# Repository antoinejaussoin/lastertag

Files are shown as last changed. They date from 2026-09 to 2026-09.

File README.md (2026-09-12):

# Lastertag

An open, custom-built laser-tag system based on the Raspberry Pi Pico 2 W.

> Despite the name, this project uses eye-safe infrared LEDs rather than laser
> diodes. Never substitute a laser module for the infrared emitter.

The initial reference build supports two players and is designed to scale to
`N` players. Each player has:

- one Pico 2 W controlling the gun, display, and all body sensors;
- four wired, body-mounted infrared receiver zones.

A local web application coordinates games, displays live statistics, and
persists match history.

## Repository layout

- [`projects/lasertag/source/`](projects/lasertag/source/) — embedded firmware, shared protocol code, and web app
- [`projects/lasertag/hardware/`](projects/lasertag/hardware/) — electronics notes and future 3D-printable parts
- [`projects/temperature-display/`](projects/temperature-display/) — first hardware sandbox: Pico 2 W temperature on the OLED
- [`projects/ir-capture/`](projects/ir-capture/) — TSOP38238 sandbox: TV-remote capture on the OLED and HTTP POST
- [`projects/gun/`](projects/gun/) — handheld laser-tag gun: ir-sender firmware in a printable Glock-17 shell
- [`docs/`](docs/) — architecture, project plan, and purchasing guide

Start with the [high-level plan](docs/high-level-plan.md), then use the
[shopping list](docs/shopping-list.md) for the two-player prototype. The
[Pico 2 W capabilities guide](docs/pico-w-capabilities.md) explains what runs
on each player controller, its memory, storage, networking, and limitations.

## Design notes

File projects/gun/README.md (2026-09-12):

# Laser-tag gun

Handheld IR gun based on the [`ir-sender`](../ir-sender/) experiment. Firmware
is the same NEC button-to-LED behaviour for now; hardware diverges into a
soldered assembly and a Glock 17–proportioned printable shell.

Leave [`ir-sender`](../ir-sender/) and [`ir-capture`](../ir-capture/) as they
are. This folder is the place to evolve the gun.

## What you need

Electronics you already have (shopping list):

- Raspberry Pi Pico 2 W (with headers)
- 0.96" I²C OLED
- Vishay TSAL6200 IR LED
- BC337-40, two 15 Ω (1 W), one 220 Ω, one 10 kΩ
- 100 nF ceramic and 4.7 µF electrolytic (decoupling at the LED)
- Diptronics DTS-644K tactile switch (trigger)
- 500 mAh LiPo with JST-PH

Extras for the permanent build (see [`hardware/README.md`](hardware/README.md)):

- soldering tools, stranded hookup wire, heat-shrink
- JST-PH 2.0 mm female pigtail
- Schottky diode (1N5817 or similar) for battery → VSYS
- M2×8 screws, bright filament + orange for the muzzle

The Adafruit PiCowbell stays on the bench as a **charging dock**. It does not
fit in the grip. Remove the dummy magazine, unplug the cell, charge on the
PiCowbell.

## Pin map (unchanged from ir-sender)

| Function | Pico | Notes |
|---|---|---|
| OLED SDA | GP16 | I²C |
| OLED SCL | GP17 | I²C |
| IR LED base drive | GP18 | through 220 Ω → BC337 |
| Trigger | GP19 | to GND through the switch; internal pull-up |
| Logic supply | 3V3 (pin 36) | OLED and IR LED path |
| Ground | GND (pin 38) | common |
| Battery | VSYS (pin 39) | via Schottky from the mag JST |
| USB 5 V | VBUS (pin 40) | leave empty |

## Hardware and CAD

- [`hardware/README.md`](hardware/README.md) — gap list, power rules, soldering
- [`hardware/connections.svg`](hardware/connections.svg) — soldered nets (no breadboard)
- [`cad/README.md`](cad/README.md) — print settings and assembly
- [`cad/gun.scad`](cad/gun.scad) — printable Glock-17-proportioned shell

## Safety

- Infrared LED only. Never substitute a laser diode.
- Power the OLED and IR LED from **3.3 V**, not `VBUS`.
- Battery `+` goes through a Schottky diode into **VSYS**. Never wire the cell
  straight across USB 5 V.
- **Remove the magazine before plugging Micro-USB into the Pico.**
- Charge the LiPo on the PiCowbell where you can watch it. Do not use a
  swollen, punctured, or hot cell.

## What the firmware does

Same as ir-sender: each trigger press sends three NEC frames (address `0x42`,
command random 1–10). The OLED shows `gun` / `ready` / `sent 42:xx`. Optional
USB serial `debug on` / `save` toggles DC / 1 s beacon modes for a meter.

Point the muzzle at an [`ir-capture`](../ir-capture/) board; it should show
`42:01`–`42:0A`.

## Build and upload

1. Hold **BOOTSEL** on the Pico, plug USB (cable must be data-capable), release.
2. Finder should show **RP2350**.
3. From the repository root:

```bash
cd projects/gun
make
```

That builds `gun.uf2` and copies it onto the drive. Or `make uf2` and drag the
file yourself.

First build downloads crates and can take several minutes.

## USB serial

```bash
ls /dev/cu.usbmodem*
screen /dev/cu.usbmodem* 115200
```

Banner: `Pico 2 W gun`. Leave `screen` with `Ctrl-A` then `K`, then `Y`.

## Next steps (not this folder yet)

Game firmware, Wi-Fi, body receivers, and the player pin map (GP0 / GP2 / …)
live later under `projects/lasertag/`. Keep this pinout until then so the
soldered harness stays compatible with the current UF2.

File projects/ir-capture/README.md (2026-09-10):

# IR-capture experiment

A standalone hardware test, separate from the laser-tag firmware. It reads a
Vishay TSOP38238 38 kHz infrared receiver, shows each captured remote button
on the 0.96" I²C OLED, and POSTs the same event to the HTTP listener used by
[`temperature-display`](../temperature-display/).

You do not need to know Rust or electronics already. Follow the steps in order.
If the OLED is already wired from the temperature test, leave those four wires
and add only the receiver.

## What you need

- Raspberry Pi Pico 2 W (RP2350 plus onboard 2.4 GHz Wi-Fi)
- a **2.4 GHz** Wi-Fi network (the Pico cannot join 5 GHz-only access points)
- 0.96" four-pin I²C OLED (the same module as the temperature test)
- Vishay TSOP38238 38 kHz IR receiver (Pi Hut)
- 100 Ω resistor, 100 nF ceramic capacitor, and 4.7 µF electrolytic capacitor
  from the shopping list (the TSOP supply filter)
- a TV remote, or any 38 kHz IR remote
- the full-size breadboard and jumper wires from the shopping list
- a **data** USB cable (charge-only cables will not work)

The PiCowbell and LiPo are not used for this test. USB powers the Pico.

## Safety

- Unplug USB while you insert parts.
- Power the OLED and the TSOP from **3.3 V only**. Do not use `VBUS`
  (physical pin 40, the 5 V USB pin).

## How to plug it together

Two drawings in this folder:

- [`connections.svg`](connections.svg) — what joins to what, no breadboard
- [`wiring.svg`](wiring.svg) — the same circuit, hole by hole on the breadboard

Useful references:

- [Interactive Pico pinout](https://pico.pinout.xyz/) — choose Pico 2 W; hover GP16, GP17, GP18, 3V3, GND
- [Pi Hut TSOP38238](https://thepihut.com/products/ir-infrared-receiver-tsop38238)
- [Vishay TSOP382 datasheet](https://www.vishay.com/docs/82491/tsop382.pdf) — pin 1 `OUT`, pin 2 `GND`, pin 3 `VS`
- [Pi Hut 0.96" OLED](https://thepihut.com/products/0-96-oled-display-module-128x64)
- [Raspberry Pi Pico getting started](https://www.raspberrypi.com/documentation/microcontrollers/pico-series.html) — BOOTSEL / UF2 upload

### TSOP38238 pinout

Hold the part with the **rounded lens toward you** and the three legs pointing
down. Left to right:

| Leg | Name | Goes to |
|---|---|---|
| left | `OUT` | Pico `GP18` (physical pin 24) |
| middle | `GND` | Pico `GND` (physical pin 38) |
| right | `VS` | Pico `3V3` through 100 Ω, with capacitors to `GND` |

The output is idle-high and goes low while a 38 kHz burst is in view. The chip
has an internal pull-up; firmware also enables the Pico pull-up.

### Assembly

Unplug USB. Hold the breadboard so **printed column 1 is on the left**. Follow
[`wiring.svg`](wiring.svg) hole for hole. Yellow holes on the drawing already
have something in them.

1. Sit the Pico 2 W **across the centre trench**, like a DIP chip. USB hangs
   off the left so the cable still fits. 20 pins go in **row e** (columns 1–20)
   and 20 pins go in **row f**. The antenna is at column 20.

   | Pico pin | Hole | Name |
   |---|---|---|
   | 1 | `e1` | GP0 |
   | 21 | `f20` | GP16 (SDA) |
   | 22 | `f19` | GP17 (SCL) |
   | 24 | `f17` | GP18 (IR) |
   | 36 | `f5` | 3V3 |
   | 38 | `f3` | GND |
   | 40 | `f1` | VBUS — leave empty |

2. Power the long rails from the Pico, then join top and bottom:

   | Colour | From | To |
   |---|---|---|
   | red | `j5` | bottom `+3V3` rail |
   | black | `j3` | bottom `GND` rail |
   | red | bottom `+` column 35 | top `+` column 35 |
   | black | bottom `GND` column 34 | top `GND` column 34 |

3. OLED pins in **`a23` `a24` `a25` `a26`**. Typical Pi Hut order is
   `VCC`, `GND`, `SCL`, `SDA`. If your module prints a different order, keep
   those four holes and move the wires to the printed names.

   The screen uses the **same GPIOs as temperature-display**: `GP16` (SDA) and
   `GP17` (SCL). If those four wires already work, leave them.

   | OLED name | Hole | Jumper |
   |---|---|---|
   | `VCC` | `a23` | top `+3V3` rail |
   | `GND` | `a24` | top `GND` rail |
   | `SCL` | `e25` | `g19` (GP17) |
   | `SDA` | `e26` | `g20` (GP16) |

4. TSOP38238 legs in **`c28` `c29` `c30`**. Lens toward you (toward the
   trench). With the lens facing you, left to right is `OUT`, `GND`, `VS`.

   | Part | Holes |
   |---|---|
   | TSOP `OUT` / `GND` / `VS` | `c28` / `c29` / `c30` |
   | orange jumper `OUT` → GP18 | `d28` → `g17` |
   | black jumper TSOP `GND` | `a29` → top `GND` rail |
   | 100 Ω from `+3V3` into `VS` | top `+` column 30 → `a30` |
   | 100 nF ceramic | `d30` – `d31` (either way) |
   | 4.7 µF electrolytic | `e30` (+) – `e31` (stripe / minus) |
   | black jumper, capacitor return | `a31` → top `GND` rail |

Do not add extra links between columns 28, 29, and 30. That would short `OUT`
or `VS` to `GND`.

The 100 Ω resistor has no polarity. The ceramic capacitor (often marked `104`)
has no polarity. The electrolytic can is polarized: the stripe is negative.

Rows `a`–`e` in one numbered column are already joined. Rows `f`–`j` in that
column are a second, separate strip. That is why a jumper in `g17` is already
connected to Pico pin 24 in `f17`.

The receiver uses `GP18` so it sits on the same Pico edge as the OLED (`GP16`
and `GP17`). The later player board maps body receivers to `GP10`–`GP13`
instead.

## What the firmware does

The TSOP38238 demodulates 38 kHz infrared. The program waits for a burst,
records mark/space times, and:

- decodes **Samsung** TV remotes (`S` plus address and command in hex);
- decodes **NEC** remotes (address and command in hex);
- shows anything else as the first two pulse times in milliseconds;
- treats a held Samsung or NEC button as a repeat (` r` on the OLED).

If the first burst does not decode (TSOP AGC, or a copy caught mid-frame),
the firmware waits for the sender’s extra copies before showing `raw`.

The title ends with **`H`** or **`L`**: the receiver output is idle-high, so
`H` means the pin looks healthy. `L` at rest means `OUT` is stuck low
(wrong pin, swapped `OUT`/`VS`, or a short). The number at the top right
counts each logical message (a held remote ` r` does not add another; the
sender’s three NEC copies count as one).

Wi-Fi SSID, password, and the HTTP POST URL are **not** compiled in. You type
them over USB serial; `save` stores them in flash. After a reboot they are
still there. Flash layout matches `temperature-display`, so a Pico that was
already provisioned for that project keeps its Wi-Fi settings.

Once joined, each captured button POSTs JSON to that URL, for example:

```json
{"proto":"samsung","addr":57504,"cmd":26,"rep":false}
```

```json
{"proto":"nec","addr":32,"cmd":13,"rep":false}
```

or, if the burst is neither:

```json
{"proto":"raw","n":67,"lead":[4500,4500]}
```

The onboard LED (on the wireless chip) turns on when Wi-Fi is up.

## Install the software tools (once)

Same tools as [`temperature-display`](../temperature-display/README.md). If
Rust is already installed, skip to **Build and upload**.

### 1. Install Rust

On macOS, in Terminal:

```bash
curl --proto '=https' --tlsv1.2 -sSf https://sh.rustup.rs | sh
```

Follow the prompts (the default options are fine). Then close Terminal and open
a new one, or run:

```bash
source "$HOME/.cargo/env"
```

Check:

```bash
rustc --version
cargo --version
```

### 2. Add the Pico 2 W CPU target

This crate’s `rust-toolchain.toml` asks `rustup` to install
`thumbv8m.main-none-eabihf` when you enter the folder. You can also install it
yourself:

```bash
rustup target add thumbv8m.main-none-eabihf
```

That target is the Pico 2 W’s ARM Cortex-M33 CPU.

## Build and upload

Put the Pico 2 W in bootloader mode first:

1. Unplug the USB cable.
2. Hold the **BOOTSEL** button on the Pico (the small button next to the USB
   socket).
3. Plug the USB cable in while still holding BOOTSEL.
4. Release BOOTSEL.
5. Finder should show a drive called **RP2350**.

If nothing appears, the cable is probably charge-only. Try another cable.

Then, from the `lastertag` repository root:

```bash
cd projects/ir-capture
make
```

That compiles the firmware, converts it to a `.uf2`, and copies it onto the
Pico. The `RP2350` drive disappears; that is normal. The program starts
immediately.

The first build downloads crates and can take several minutes. After that,
`make` is the only command you need when the board is already in BOOTSEL.

If `make` builds the UF2 but cannot copy it, drag `ir-capture.uf2` onto the
**RP2350** drive in Finder.

If you only want the files without copying them onto the board:

```bash
make build   # ELF only
make uf2     # ELF plus ir-capture.uf2
```

## What you should see

Text on the OLED, similar to:

```text
IR capture  H          0
  ready
USB: wifi/save
```

Point a TV remote at the TSOP lens and press a button. A Samsung TV remote
usually looks like this (address is often `E0E0`):

```text
IR capture  H          1
  S E0E0:1A
wifi ok  post ok
```

A typical NEC remote shows address and command without the `S`:

```text
IR capture  H          2
  20:0D
wifi ok  post ok
```

Holding the button adds ` r`. Other 38 kHz encodings show the first two
pulse lengths, for example `4.5 4.5 67` (milliseconds, then edge count).

The bottom line is status: `joining wifi`, `wifi ok`, `wifi fail`, or
`wifi ok  post ok` after a successful POST.

On a dual-colour 0.96" panel the top band is yellow and the rest is blue.
The title sits in the yellow band; the hex value is blue. That is the glass,
not a wiring fault.

If every press shows times like `4.5 4.5` instead of `S …`, the header is
Samsung-like but the bit timings did not match; the JSON still has the lead
times.

## USB Wi-Fi and server setup

Flash the board, wait until the OLED is showing `ready`, then open a serial
terminal. On macOS:

```bash
ls /dev/cu.usbmodem*
screen /dev/cu.usbmodem* 115200
```

If several `usbmodem` devices appear, try each until you see a `>` prompt.
Type `help`. Leave `screen` with `Ctrl-A` then `K`, then `Y`.

On this computer, start a listener (binds all interfaces, port 8090). This is
the same program as in `temperature-display`; you only need one copy running:

```bash
bun listen_post.ts
```

It prints this machine’s LAN IP. On the Pico console, using that IP:

```text
wifi YourNetworkName
psk YourPassword
server 192.168.1.23:8090/ir
save
```

You can keep path `/temp` if this Pico was already set up for the temperature
project; the listener accepts any POST path. `psk` with no password means an
open network. `server` can also be a hostname (`nas.local:8090/ir`). The Pico
is 2.4 GHz only.

`save` writes flash and starts joining. `show` prints the current RAM copy.
`clear` wipes the saved settings. After `save`, you can unplug USB and power
from the PiCowbell; the board still has the settings.

Press a remote button. The listener should print a JSON body. The Pico talks
to your **LAN IP**, not `localhost`.

SH1106 panels have 132 columns of RAM and 128 visible. This firmware starts
the write window at column 0 so the left edge is not leftover RAM. If a 2-pixel
bar appears on the **right** instead, change `with_column_offset(0)` in
`src/display.rs` to `with_column_offset(2)` and flash again.

## If the title is readable but the rest is noise

The firmware talks to the panel as an **SH1106** (132-column RAM). Cheap
yellow/blue 0.96" modules are often SH1106 even when the listing says
SSD1306. Driving SH1106 as SSD1306 commonly leaves the first rows readable
and fills the blue area with random pixels.

Reflash this folder with BOOTSEL + `make`. If the value is still garbage, in
`src/display.rs` change `OledConfig::sh1106_128x64()` to
`OledConfig::ssd1306_128x64()` and flash again.

## If the screen stays black

- USB is plugged into the Pico (the board is powered from that cable).
- Every OLED label matches the table. Swapping SDA/SCL is the most common
  mistake.
- `VCC` is on **3V3** (pin 36), not **VBUS** (pin 40).
- You counted pins from the USB end. `GP16`/`GP17` are on the **right** side,
  at the end opposite the USB plug.
- You actually copied a UF2 (the `RP2350` drive vanished after the copy).
- Some modules use I²C address `0x3D` instead of `0x3C`. In `src/display.rs`,
  change the `0x3C` passed to `Oled::new` to `0x3D`.
- The plastic film on a new OLED can make it look dim; peel it off.

## If nothing happens when you press the remote

Samsung remotes are the usual case here. Older IR-only Samsung remotes speak
**Samsung32** (not NEC). This firmware decodes that after you reflash. Many
**Samsung Smart / One Remote** handsets are Bluetooth: only a few keys still
emit IR (often **Power**). Try Power first, close to the lens. A cheap IR-only
TV remote is a better test.

Also check:

- You flashed **this** folder after the `GP18` pin change (`BOOTSEL` + `make`).
  An older UF2 still listens on a different GPIO.
- The title shows **`H`** at rest. If it shows **`L`**, `OUT` is stuck low:
  confirm the orange jumper is `d28` → `g17` (Pico pin 24 / `GP18`), and that
  the TSOP legs are `OUT`, `GND`, `VS` left to right with the lens toward you.
  Swapping `OUT` and `VS` can make the part hot; unplug USB and recheck.
- The first press after a long idle can be eaten by the TSOP AGC. Press again.
- `VS` is 3.3 V through 100 Ω, not 5 V. The electrolytic stripe is on **GND**.
- The TSOP38238 is a 38 kHz part. It ignores 56 kHz gadgets; 36 kHz remotes
  only work at very short range.
- Range is typically tens of centimetres to a few metres. Point at the **lens**,
  not the Pico or the table, and avoid a bright lamp straight into the lens.

## Changing the program

Edit `src/main.rs` or `src/ir.rs`, save, put the Pico back in BOOTSEL, then
`make` again.

This folder is only a sandbox. Game firmware will live later under
`projects/lasertag/source/firmware/`.

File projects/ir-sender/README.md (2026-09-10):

# IR-sender experiment

A standalone hardware test, separate from the laser-tag firmware. It sits on
the **second** Pico 2 W. Press a button and it blinks the infrared LED with a
NEC remote code. The [`ir-capture`](../ir-capture/) board should show `42:01`–`42:0A`.

Leave ir-capture assembled. Do not unplug that breadboard.

You do not need to know Rust or electronics already. Follow the steps in order.

## What you need

- the **second** Raspberry Pi Pico 2 W (keep the first one running ir-capture)
- 0.96" four-pin I²C OLED (the second module from the shopping list)
- Vishay TSAL6200 940 nm IR LED (Rapid)
- one Diotec **BC337-40** transistor
- two **15 Ω, 1 W** resistors (brown-green-black)
- one **220 Ω** resistor (red-red-brown) — GPIO to the transistor **base** only
- one **10 kΩ** resistor (brown-black-orange) — base to GND
- one tactile push button (Diptronics DTS-644K)
- the second full-size breadboard and jumper wires
- a **data** USB cable (charge-only cables will not work)

The PiCowbell and LiPo are **not** used here. USB powers the Pico.

## Safety

- Unplug USB while you insert parts.
- Power the OLED from **3.3 V only**. Do not use `VBUS` (physical pin 40, the
  5 V USB pin).
- The two 15 Ω resistors feed the LED from **3.3 V** through the transistor.
  Never put a 15 Ω resistor on GP18. The 220 Ω is only between GP18 and the
  base.

## How to plug it together

Two drawings in this folder:

- [`connections.svg`](connections.svg) — three diagrams (OLED, button, TSAL), Pico on each, no breadboard
- [`wiring.svg`](wiring.svg) — the same circuit, hole by hole on the breadboard

Useful references:

- [Interactive Pico pinout](https://pico.pinout.xyz/) — choose Pico 2 W; hover GP16, GP17, GP18, GP19, 3V3, GND
- [Pi Hut 0.96" OLED](https://thepihut.com/products/0-96-oled-display-module-128x64)
- [Vishay TSAL6200](https://www.rapidonline.com/vishay-tsal6200-5mm-940nm-ir-transmitter-diode-49-4513) — long lead is the anode
- [Raspberry Pi Pico getting started](https://www.raspberrypi.com/documentation/microcontrollers/pico-series.html) — BOOTSEL / UF2 upload

### TSAL6200 pinout

Looks like a clear or smoke-grey 5 mm LED:

| Leg | Name | Goes to |
|---|---|---|
| long | anode (`A`) | two 15 Ω from `+3V3` |
| short, next to the flat rim | cathode (`K`) | BC337 collector |

### BC337-40 pinout

Small black TO-92, one flat face, three legs. For the Diotec part, with the
**flat toward you** and the legs down, the order is **C-B-E** (left to right).
On this breadboard, point the flat at the **trench** and use
`c26` = C, `c25` = B, `c24` = E. All IR parts stay in rows `a`–`d`.

### Assembly

Unplug USB. Hold the breadboard so **printed column 64 is on the left** (Pico /
USB) and **column 1 is on the right**. The Pico sits **lower**: pins in **row
`e`** (above the trench) and **row `j`** (below the trench). On this board the
lower letters run `j` `i` `h` `g` `f` from the trench down. Top rails are `+`
then `−`. After row `f`, the bottom rails are `+` then `−` at the very bottom.

Follow [`wiring.svg`](wiring.svg) hole for hole. Yellow holes on the drawing
already have something in them. If your last printed number is 63, not 64,
shift every hole one column toward the Pico.

1. Sit the Pico 2 W **across the centre trench**, like a DIP chip. USB hangs
   off the left at column 64 so the cable still fits. 20 pins go in **row e**
   (columns 64–45) and 20 pins go in **row j**. The antenna is at column 45.

   With the chip facing you and USB on the left, the **top** row (e) is pins
   40–21 and the **bottom** row (j) is pins 1–20. GP16–GP19 are on the top.

   | Pico pin | Hole | Name |
   |---|---|---|
   | 40 | `e64` | VBUS — leave empty |
   | 38 | `e62` | GND |
   | 36 | `e60` | 3V3 |
   | 25 | `e49` | GP19 (button) |
   | 24 | `e48` | GP18 (IR LED) |
   | 23 | `e47` | GND — skip this column |
   | 22 | `e46` | GP17 (SCL) |
   | 21 | `e45` | GP16 (SDA) |
   | 1 | `j64` | GP0 |

2. Power the long rails from the Pico, then join top and bottom:

   | Colour | From | To |
   |---|---|---|
   | red | `a60` | top `+` rail |
   | black | `a62` | top `−` rail |
   | red | bottom `+` column 20 | top `+` column 20 |
   | black | bottom `−` column 19 | top `−` column 19 |

3. OLED pins in **`a42` `a41` `a40` `a39`**, from the Pico toward column 1.
   Typical Pi Hut order is `VCC`, `GND`, `SCL`, `SDA`. If your module prints a
   different order, keep those four holes and move the wires to the printed
   names.

   | OLED name | Hole | Jumper |
   |---|---|---|
   | `VCC` | `a42` | top `+` rail |
   | `GND` | `a41` | top `−` rail |
   | `SCL` | `c40` | `c46` (GP17) |
   | `SDA` | `d39` | `d45` (GP16) |

4. IR driver on the **top** half (rows `a`–`d`), **to the right of the OLED**.
   Q1 needs three consecutive holes of its own. Unplug USB first. Pull the old
   IR parts if they were in columns 37–32 — those holes stacked the LED on
   top of Q1, so the middle leg (B) often never sat in its strip.

   | Part | Holes |
   |---|---|
   | BC337-40, flat toward the trench | `c26` C, `c25` B, `c24` E |
   | red jumper +3V3 → first 15 Ω | top `+` column 37 → `b37` |
   | 15 Ω | `b37` – `b32` |
   | 15 Ω | `b32` – `b28` |
   | TSAL6200 anode / cathode | `c28` / `c26` (cathode shares C) |
   | orange jumper GP18 → 220 Ω | `b48` → `d21` |
   | 220 Ω (base) | `d21` – `d25` |
   | 10 kΩ base pull-down | `a25` → top `−` rail |
   | black jumper emitter → GND | `a24` → top `−` rail |

   Long LED lead in `c28`. Short lead and flat rim in `c26`.

   A meter on **B** (`c25`) while GP18 is high must read about **0.7 V**. If
   that hole is still **3.3 V**, the middle transistor leg is not in `c25`.

   Bands: 15 Ω is **brown-green-black**. 220 Ω is **red-red-brown**. 10 kΩ is
   **brown-black-orange**. A 15 Ω on GP18 can damage the Pico.

5. Button across the trench (legs in `e` and `j`). On this 6×6 part the
   **6.5 mm** pins are already joined inside the switch. Those pins are the
   ones that span the trench, so `e31` is permanently connected to `j31`.
   Ground must **not** be on `j31` — that holds GP19 low forever.

   GP19 and GND both sit on the **top** half, two columns apart. Press joins
   column 31 to column 29.

   | Part | Holes |
   |---|---|
   | button legs | `e31` `e29` `j31` `j29` |
   | purple jumper GP19 | `d49` → `d31` |
   | black jumper to GND | `d29` → top `−` rail |

   Leave `j31` without a GND wire. Keep the switch off column 32 (15 Ω
   midpoint).

Rows `a`–`e` in one numbered column are already joined. Rows `j`–`f` in that
column are a second, separate strip. That is why a jumper in `b48` is already
connected to Pico GP18 in `e48`.

## What the firmware does

GP18 is a GPIO into the BC337 base. Marks are a 38 kHz square wave on that
pin; spaces are the pin low (transistor off). The LED itself runs from 3.3 V
at about 58 mA. On each button press the program sends three **NEC** frames: address
`0x42` and a **command rolled at random from 1 to 10**. ir-capture already
understands that encoding, so its OLED should show `42:01` … `42:0A` and
its HTTP POST looks like:

```json
{"proto":"nec","addr":66,"cmd":7,"rep":false}
```

(`cmd` is decimal 1–10.) The Pico’s onboard LED lights for half a second
on each press (that LED is on the wireless chip, not the IR LED).

A held button does not repeat. Release and press again for another burst.

Boot starts at `ready`. There is no Wi-Fi on this board. A USB serial CLI
(same idea as capture’s Wi-Fi setup) can turn on a **debug** mode for a meter:

```text
debug on
save
```

Then the button toggles **`always on`** (LED DC, ~58 mA, TSOP ignores it) and
**`every 1s`** (a random NEC `42:01`–`42:0A` once a second). `debug off` then `save` returns to
one NEC per click. `show` / `clear` work like capture. After `save`, the flag
survives reboot.

Keep phones **away from the capture TSOP**. An iPhone’s Face ID / LiDAR
illuminator is also 940 nm; that chip will report short garbled `raw` bursts
that have nothing to do with this LED.

## Install the software tools (once)

Same tools as [`ir-capture`](../ir-capture/README.md). If Rust is already
installed, skip to **Build and upload**.

### 1. Install Rust

On macOS, in Terminal:

```bash
curl --proto '=https' --tlsv1.2 -sSf https://sh.rustup.rs | sh
```

Follow the prompts (the default options are fine). Then close Terminal and open
a new one, or run:

```bash
source "$HOME/.cargo/env"
```

Check:

```bash
rustc --version
cargo --version
```

### 2. Add the Pico 2 W CPU target

This crate’s `rust-toolchain.toml` asks `rustup` to install
`thumbv8m.main-none-eabihf` when you enter the folder. You can also install it
yourself:

```bash
rustup target add thumbv8m.main-none-eabihf
```

That target is the Pico 2 W’s ARM Cortex-M33 CPU.

## Build and upload

Put **this** Pico 2 W in bootloader mode first (the sender board, not the
capture board):

1. Unplug the USB cable.
2. Hold the **BOOTSEL** button on the Pico (the small button next to the USB
   socket).
3. Plug the USB cable in while still holding BOOTSEL.
4. Release BOOTSEL.
5. Finder should show a drive called **RP2350**.

If nothing appears, the cable is probably charge-only. Try another cable.

Then, from the `lastertag` repository root:

```bash
cd projects/ir-sender
make
```

That compiles the firmware, converts it to a `.uf2`, and copies it onto the
Pico. The `RP2350` drive disappears; that is normal. The program starts
immediately.

The first build downloads crates and can take several minutes. After that,
`make` is the only command you need when the board is already in BOOTSEL.

If `make` builds the UF2 but cannot copy it, drag `ir-sender.uf2` onto the
**RP2350** drive in Finder.

If you only want the files without copying them onto the board:

```bash
make build   # ELF only
make uf2     # ELF plus ir-sender.uf2
```

## What you should see

Right after flash, the **sender** OLED shows:

```text
IR sender    H
  ready
press btn
```

The title must end in **`H`** at rest. Hold the button: it should switch to
**`L`** for as long as you hold. If it is **`L` at rest**, the black GND
jumper is still on `j31` — move it to **`d29` → top −**. Do not ground `j31`.

Press the button. The onboard LED lights for 0.5 s and the line changes to
`sent 42:07` (command is random 1–10, shown in hex). The number in the top
right is how many times you have pressed.

On the **capture** Pico, pointed at this LED from a short distance:

```text
IR capture  H          1
  42:07
wifi ok  post ok
```

(`wifi ok  post ok` only if that Pico is already joined to Wi-Fi.)

On a dual-colour 0.96" panel the top band is yellow and the rest is blue.
The title sits in the yellow band. That is the glass, not a wiring fault.

## USB serial debug setup

Debug mode is **off** by default. Leave it off for the real test: one button
click sends one NEC burst and stops.

Flash the sender, wait until the OLED shows `ready`, then open a serial
terminal. On macOS:

```bash
ls /dev/cu.usbmodem*
screen /dev/cu.usbmodem* 115200
```

Capture and sender both appear as `usbmodem` devices. Try each until the
banner says `Pico 2 W IR sender`. Type `help`. Leave `screen` with `Ctrl-A`
then `K`, then `Y`.

```text
debug on
save
```

`save` writes flash and applies now. The OLED switches to `always on` (LED
DC, ~58 mA — the capture TSOP ignores DC). Press the button to toggle
`every 1s` (a random NEC `42:01`–`42:0A` once a second). Press again to go back to DC.

```text
debug off
save
```

That returns to one NEC per click. `show` prints the RAM copy. `clear` wipes
the saved flag. After `save`, the setting survives reboot.

Range is tens of centimetres, not metres. Point the LED at the TSOP **lens**.
The LED does not light visibly; infrared is outside human vision.

## If the title is readable but the rest is noise

The firmware talks to the panel as an **SH1106** (132-column RAM). Cheap
yellow/blue 0.96" modules are often SH1106 even when the listing says
SSD1306. Driving SH1106 as SSD1306 commonly leaves the first rows readable
and fills the blue area with random pixels.

Reflash this folder with BOOTSEL + `make`. If the value is still garbage, in
`src/display.rs` change `OledConfig::sh1106_128x64()` to
`OledConfig::ssd1306_128x64()` and flash again.

SH1106 panels have 132 columns of RAM and 128 visible. This firmware starts
the write window at column 0 so the left edge is not leftover RAM. If a 2-pixel
bar appears on the **right** instead, change `with_column_offset(0)` in
`src/display.rs` to `with_column_offset(2)` and flash again.

## If the screen stays black

- USB is plugged into the Pico (the board is powered from that cable).
- Every OLED label matches the table. Swapping SDA/SCL is the most common
  mistake.
- `VCC` is on **3V3** (pin 36), not **VBUS** (pin 40).
- You counted pins from the USB end. `GP16`/`GP17` are on the **top** row,
  at the end opposite the USB plug (`e45` / `e46`).
- You actually copied a UF2 (the `RP2350` drive vanished after the copy).
- Some modules use I²C address `0x3D` instead of `0x3C`. In `src/display.rs`,
  change the `0x3C` passed to `Oled::new` to `0x3D`.
- The plastic film on a new OLED can make it look dim; peel it off.

## If the OLED stays on `L` / `btn down`

GP19 is shorted to GND. On this switch the legs that cross the trench are
already joined inside the part, so a GND wire on **`j31`** holds the pin low
even when you are not pressing.

1. Unplug the black jumper from `j31`. The title should become **`H`**.
2. Plug that black jumper **`d29` → top −** (same half of the board as
   purple, one column toward the LED). Leave `j31` empty of GND.
3. Rest = `H`. Hold = `L`. Then a press sends IR.

## If the button only works rarely

Watch the title **`H` / `L`** while you press. Rest must be **`H`**.

1. Rest is `L`: follow the section above (`d29`, not `j31`).
2. Rest is `H` but a hold stays `H`: push all four legs in, reseat purple
   `d49`–`d31` and black `d29`.

## If capture shows nothing, or raw times instead of `42:xx`

- After flash, OLED must say `ready` (otherwise this UF2 is not on the board).
  Point the LED at the capture TSOP and press: you should get `42:01`–`42:0A`.
  The capture title’s right-hand number should increment once per press. For a
  meter, USB serial `debug on` then `save` — OLED `always on` is DC (capture
  will not show `L`). Button then toggles `every 1s`. Still nothing: Q1 flat
  toward the trench (`c26` C, `c25` B, `c24` E), long LED lead in `c28`, orange
  jumper from `b48` (GP18) not column 47, 15 Ω only in the 3.3 V LED path.
  If GP18 is 3.3 V but **B (`c25`) is also 3.3 V**, the middle Q1 leg is not
  in `c25` — a real base clamps at ~0.7 V.
- Do **not** hold an iPhone (or any Face ID / LiDAR phone) near the capture
  TSOP. That illuminator is 940 nm and shows up as short `raw` junk. A TV
  remote is the right “capture still works” check.
- Point the LED at the TSOP lens on the other breadboard, a few centimetres
  away. Do not aim at the Pico or the table. A phone camera is a wiring test,
  not a protocol test: 38 kHz bursts are too short and too dim to trust.
- The orange jumper must be column **48 on the top** (`b48`), the same strip
  as Pico `e48` / GP18. Column **47** on that row is GND — an easy miss.
- Long LED lead is in `c28` (anode). Cathode must sit on the collector (`c26`),
  not on GND.
- The 220 Ω is `d21`–`d25` (base). The 15 Ω pair is `b37`–`b32`–`b28`.
- You flashed **this** folder (`projects/ir-sender`) onto the sender Pico, and
  ir-capture is still running on the other Pico.
- Capture’s title shows **`H`** at rest. If it shows **`L`**, that board’s
  receiver wiring is wrong; see the ir-capture README.

## Changing the program

Edit `src/main.rs` or `src/ir.rs`, save, put the Pico back in BOOTSEL, then
`make` again.

This folder is only a sandbox. Game firmware will live later under
`projects/lasertag/source/firmware/`. The player board uses this same
transistor driver on GP0.

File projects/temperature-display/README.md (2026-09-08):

# Temperature-on-OLED experiment

A standalone first hardware test, separate from the laser-tag firmware. It
reads the temperature sensor **inside** the Raspberry Pi Pico 2 W and shows it
on the 0.96" I²C OLED.

You do not need to know Rust or electronics already. Follow the steps in order.

## What you need

- Raspberry Pi Pico 2 W (RP2350 plus onboard 2.4 GHz Wi-Fi)
- a **2.4 GHz** Wi-Fi network (the Pico cannot join 5 GHz-only access points)
- 0.96" four-pin I²C OLED (often sold as SSD1306; many yellow/blue 128×64
  modules are actually SH1106)
- the full-size breadboard and jumper wires from the shopping list
- a **data** USB cable (charge-only cables will not work)

The PiCowbell and LiPo are not used for this test. USB powers the Pico.

## Safety

- Unplug USB while you insert parts.
- Power the OLED from **3.3 V only**. Do not use `VBUS` (physical pin 40, the
  5 V USB pin).

## How to plug it together

Open the drawing in this folder:

- [`wiring.svg`](wiring.svg)

Useful references:

- [Interactive Pico pinout](https://pico.pinout.xyz/) — choose Pico 2 W; hover GP16, GP17, 3V3, GND
- [Pi Hut 0.96" OLED](https://thepihut.com/products/0-96-oled-display-module-128x64) — this module’s pins and I²C address `0x3C`
- [Raspberry Pi Pico getting started](https://www.raspberrypi.com/documentation/microcontrollers/pico-series.html) — BOOTSEL / UF2 upload

### Assembly

1. Unplug USB. Sit the Pico 2 W **across the centre gap** of the breadboard,
   like a bridge. The USB socket should hang off the top so the cable still
   fits. Count pins from that USB end. The antenna is at the opposite end
   from USB.
2. Put the OLED in four unused columns, away from the Pico, so each OLED pin
   has its own column.
3. Four jumper wires. Match the **printed names on the OLED**, not a photo of
   a different module:

   | OLED pin | Pico pin | Physical pin (USB at the top) |
   |---|---|---:|
   | `VCC` | `3V3` | 36 (fifth pin down the **right** side) |
   | `GND` | `GND` | 38 (third pin down the **right** side) |
   | `SDA` | `GP16` | 21 (bottom pin on the **right** side) |
   | `SCL` | `GP17` | 22 (second pin from the bottom on the **right** side) |

4. On a breadboard, every hole in the same numbered column (on one side of
   the gap) is already connected. Plug the jumper into the same column as the
   Pico pin, then into the OLED pin’s column.

You can ignore the long coloured power rails for this test.

## What the firmware does

The Pico 2 W has a small temperature sensor on the RP2350 silicon. The program
reads that sensor about once a second and draws the value on the OLED.

That number is the **chip** temperature. It is usually a few degrees above the
room, and it rises while the chip runs. It is not a weather reading.

Wi-Fi SSID, password, and the HTTP POST URL are **not** compiled in. You type
them over USB serial; `save` stores them in flash. After a reboot they are
still there. Once joined, the Pico POSTs `{"celsius":27.4}` about once a
minute to that URL.

The onboard LED (on the wireless chip) turns on when Wi-Fi is up.

## Install the software tools (once)

You will compile a program on your computer, then copy a small file onto the
Pico. The Pico is a microcontroller: it does not run macOS or Linux.

### 1. Install Rust

On macOS, in Terminal:

```bash
curl --proto '=https' --tlsv1.2 -sSf https://sh.rustup.rs | sh
```

Follow the prompts (the default options are fine). Then close Terminal and open
a new one, or run:

```bash
source "$HOME/.cargo/env"
```

Check:

```bash
rustc --version
cargo --version
```

### 2. Add the Pico 2 W CPU target

This crate’s `rust-toolchain.toml` asks `rustup` to install
`thumbv8m.main-none-eabihf` when you enter the folder. You can also install it
yourself:

```bash
rustup target add thumbv8m.main-none-eabihf
```

That target is the Pico 2 W’s ARM Cortex-M33 CPU.

## Build and upload

Put the Pico 2 W in bootloader mode first:

1. Unplug the USB cable.
2. Hold the **BOOTSEL** button on the Pico (the small button next to the USB
   socket).
3. Plug the USB cable in while still holding BOOTSEL.
4. Release BOOTSEL.
5. Finder should show a drive called **RP2350**.

If nothing appears, the cable is probably charge-only. Try another cable.

Then, from the `lastertag` repository root:

```bash
cd projects/temperature-display
make
```

That compiles the firmware, converts it to a `.uf2`, and copies it onto the
Pico. The `RP2350` drive disappears; that is normal. The program starts
immediately.

The first build downloads crates and can take several minutes. After that,
`make` is the only command you need when the board is already in BOOTSEL.

If `make` builds the UF2 but cannot copy it, drag
`temperature-display.uf2` onto the **RP2350** drive in Finder.

If you only want the files without copying them onto the board:

```bash
make build   # ELF only
make uf2     # ELF plus temperature-display.uf2
```

## What you should see

Text updating about once a second, similar to:

```text
Pico chip temp
  27.4 C
USB: wifi/save
```

The bottom line is status: `joining wifi`, `wifi ok`, `wifi fail`, or
`wifi ok  post ok` after a successful POST.

On a dual-colour 0.96" panel the top band is yellow and the rest is blue.
The title sits in the yellow band; the temperature number is blue. That is
the glass, not a wiring fault.

A value between about 20 °C and 45 °C at a desk is typical.

## USB Wi-Fi and server setup

Flash the board, wait until the OLED is showing a temperature, then open a
serial terminal. On macOS:

```bash
ls /dev/cu.usbmodem*
screen /dev/cu.usbmodem* 115200
```

If several `usbmodem` devices appear, try each until you see a `>` prompt.
Type `help`. Leave `screen` with `Ctrl-A` then `K`, then `Y`.

On this computer, start a listener (binds all interfaces, port 8090):

```bash
bun listen_post.ts
```

It prints this machine’s LAN IP. On the Pico console, using that IP:

```text
wifi YourNetworkName
psk YourPassword
server 192.168.1.23:8090/temp
save
```

`psk` with no password means an open network. `server` can also be a hostname
(`nas.local:8090/temp`). The Pico is 2.4 GHz only.

`save` writes flash and starts joining. `show` prints the current RAM copy.
`clear` wipes the saved settings. After `save`, you can unplug USB and power
from the PiCowbell; the board still has the settings.

The listener should print a JSON body about once a minute. The Pico talks to
your **LAN IP**, not `localhost`.

SH1106 panels have 132 columns of RAM and 128 visible. This firmware starts
the write window at column 0 so the left edge is not leftover RAM. If a 2-pixel
bar appears on the **right** instead, change `with_column_offset(0)` in
`src/main.rs` to `with_column_offset(2)` and flash again.

## If the title is readable but the rest is noise

The firmware talks to the panel as an **SH1106** (132-column RAM). Cheap
yellow/blue 0.96" modules are often SH1106 even when the listing says
SSD1306. Driving SH1106 as SSD1306 commonly leaves the first rows readable
and fills the blue area with random pixels.

Reflash this folder with BOOTSEL + `make`. If the temperature is still
garbage, in `src/main.rs` change `OledConfig::sh1106_128x64()` to
`OledConfig::ssd1306_128x64()` and flash again.

## If the screen stays black

- USB is plugged into the Pico (the board is powered from that cable).
- Every OLED label matches the table. Swapping SDA/SCL is the most common
  mistake.
- `VCC` is on **3V3** (pin 36), not **VBUS** (pin 40).
- You counted pins from the USB end. `GP16`/`GP17` are on the **right** side,
  at the end opposite the USB plug.
- You actually copied a UF2 (the `RP2350` drive vanished after the copy).
- Some modules use I²C address `0x3D` instead of `0x3C`. In `src/main.rs`,
  change the `0x3C` passed to `Oled::new` to `0x3D`.
- The plastic film on a new OLED can make it look dim; peel it off.

## Changing the program

Edit `src/main.rs`, save, put the Pico back in BOOTSEL, then `make` again.

This folder is only a sandbox. Game firmware will live later under
`projects/lasertag/source/firmware/`.

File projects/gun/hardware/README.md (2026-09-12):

# Gun hardware (soldered, no breadboard)

This is the permanent packing for [`projects/gun`](../). The electrical net
matches [`ir-sender`](../../ir-sender/) plus battery power on `VSYS`. There is
no PiCowbell and no breadboard in the shell.

Drawing: [`connections.svg`](connections.svg).

## Gap list — what you have vs what you need

### Already good enough to shoot

| Part | Role |
|---|---|
| Pico 2 W | controller, USB programming, onboard LED |
| TSAL6200 + BC337-40 + 2×15 Ω + 220 Ω + 10 kΩ | IR transmitter |
| DTS-644K | trigger |
| 0.96" I²C OLED | status display |
| 100 nF + 4.7 µF | LED supply decoupling (use them; breadboard skipped them) |
| 500 mAh LiPo (JST-PH) | portable power |

### Not in the gun (on purpose)

| Part | Why |
|---|---|
| Adafruit Proto Doubler PiCowbell | too large (~51×51 mm); keep as **bench charger** |
| Breadboard / jumper kit | replaced by soldered harness |
| Body TSOP receivers | wearable harness later |
| Extra reload / menu buttons | firmware later |

### Buy before soldering

| Item | Purpose |
|---|---|
| Soldering iron, flux, solder, cutters, strippers | assembly |
| 22 AWG stranded hookup wire (or cut solid jumpers) | flying leads |
| Heat-shrink tubing | insulation on the IR nest |
| **JST-PH 2.0 mm 2-pin female pigtail** | mates the battery in the magazine |
| **1N5817 Schottky** (or similar) | battery `+` → diode → Pico `VSYS` |
| 8–12× M2×8 screws | clamshell |
| Bright filament + orange filament | body + toy muzzle collar |

## Power rules

```text
LiPo + ──► JST female ──► Schottky anode ──► cathode ──► Pico VSYS (pin 39)
LiPo − ──► JST female ───────────────────────────────► Pico GND  (pin 38)
USB Micro ───────────────────────────────────────────► Pico USB (VBUS unused on GPIO)
```

- The Pico onboard diode already feeds USB into `VSYS`. The **extra** Schottky
  stops USB 5 V from charging the LiPo through the battery lead.
- Charge only on the PiCowbell: mag out → unplug cell JST → plug into PiCowbell
  → charge from that Pico’s USB.
- Operational rule even with the diode: **remove the magazine before plugging
  Micro-USB into the gun Pico.**
- Never connect the battery to `VBUS` (pin 40). Leave pin 40 empty.
- IR LED and OLED always from regulated **3V3** (pin 36), never from `VSYS`
  (battery voltage rises to ~4.2 V when charged and would change LED current).

## Pin map

| Net | Pico pin | Goes to |
|---|---|---|
| `+3V3` | 36 | OLED VCC, two 15 Ω, decoupling |
| `GND` | 38 | OLED GND, BC337 emitter, 10 kΩ, button, battery − |
| `VSYS` | 39 | Schottky cathode |
| `SDA` | GP16 / 21 | OLED SDA |
| `SCL` | GP17 / 22 | OLED SCL |
| `IR_TX` | GP18 / 24 | 220 Ω → BC337 base |
| `BTN` | GP19 / 25 | one side of trigger switch |
| `VBUS` | 40 | **leave open** |

Keep headers on the Pico. Solder wires onto the header pins you use; leave the
rest free so the board sits flat in the grip tray.

## BC337-40 (Diotec)

Flat face toward you, legs down: **C · B · E** left to right.

- Collector ← LED cathode (short lead / flat rim)
- Base ← 220 Ω from GP18, and 10 kΩ to GND
- Emitter → GND

## OLED

Typical Pi Hut order is `VCC GND SCL SDA`. **Read the silk on your module** —
orders vary. VCC is 3.3 V only.

## Trigger button (DTS-644K)

Four legs. The **6.5 mm** pair is already joined inside the switch. Use the
**4.5 mm** pair: one leg → GP19, other → GND. Do not also ground a permanently
joined leg or the pin stays low forever.

## Soldering sequence (three harnesses + power)

Build and heat-shrink on the bench before stuffing the shell.

### 1. IR nest (muzzle end)

Point-to-point / dead-bug, keep the high-current loop short:

1. Join the two 15 Ω in series.
2. Free end of the pair → Pico 3V3 (will run as a long lead into the grip).
3. Other end → TSAL6200 **anode** (long lead).
4. Cathode → BC337 **collector**.
5. Emitter → GND lead.
6. GP18 lead → 220 Ω → base.
7. Base → 10 kΩ → same GND.
8. 100 nF across local 3V3/GND at the LED.
9. 4.7 µF across the same nodes; **stripe / short lead = minus (GND)**.

Approximate LED current from 3.3 V with 30 Ω: ~58 mA. Safe starting value.

### 2. OLED pigtail

Four wires: VCC, GND, SCL, SDA → pins 36, 38, GP17, GP16.

### 3. Trigger

Two wires from the DTS-644K 4.5 mm pair → GP19 and GND.

### 4. Battery pigtail

- Female JST-PH hangs into the mag well.
- Red (battery +) → Schottky **anode**; cathode → VSYS (pin 39).
- Black → GND (pin 38).
- Confirm LiPo red aligns with `+` before first plug-in.

## Bench test order

1. **USB only, no battery.** Flash `projects/gun`, OLED shows `gun` / `ready`,
   title ends in `H` at rest. Press trigger → `sent 42:xx`. Capture board sees
   `42:01`–`42:0A`.
2. **Battery only, no USB.** Mag in, diode polarity correct, same behaviour.
3. Fit into the printed shell (see [`../cad/README.md`](../cad/README.md)).
4. Only then combine USB + battery if needed for serial while powered; still
   prefer mag-out when plugging USB.

## Inspection before power

1. No wire on VBUS.
2. OLED VCC on 3V3, not 5 V.
3. No 15 Ω on GP18 (only 220 Ω to the base).
4. Electrolytic polarity and LED anode/cathode correct.
5. BC337 C-B-E matched to the Diotec package.
6. Button does not short GP19 at rest (title must be `H`).

## PiCowbell charging dock

1. Power the gun off by removing the magazine.
2. Unplug the cell’s male JST from the gun’s female pigtail.
3. Plug the cell into the PiCowbell JST (red to `+`).
4. Charge from USB on the Pico seated in the PiCowbell.
5. Never charge a damaged cell.

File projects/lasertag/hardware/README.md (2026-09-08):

# Hardware

This directory is reserved for version-controlled hardware design artifacts.

## Planned structure

- `electronics/` — schematics, pin maps, power budget, PCB sources, and BOMs
- `3d-printing/` — CAD sources, exported meshes, drawings, and print notes
- `test/` — range, current, thermal, battery, and environmental test results

Only source/design files should be authoritative. Exported manufacturing files
must record the source revision, units, tolerances, and generation settings.

The first electrical artifact is the
[`electronics/player-prototype/`](electronics/player-prototype/) breadboard
schematic. It covers:

- Pico 2 W power and USB charging through an Adafruit Proto Doubler PiCowbell;
- transistor-driven 940 nm IR emitter;
- four separately addressable 38 kHz receiver inputs;
- 3.3 V I²C OLED and buttons;
- receiver filtering, pin allocation, assembly checks, and test points.

Do not connect a laser diode. Do not drive an emitter LED from a GPIO pin.

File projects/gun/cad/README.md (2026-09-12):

# CAD — printable gun shell

Glock 17 Gen5 proportions with pockets sized for the Pico 2 W, OLED, LiPo
magazine, IR LED, and trigger. Source: [`gun.scad`](gun.scad).

This is a **toy IR marker**, not a firearm replica: bright body colour, orange
muzzle collar, no trademarks or serial markings. The frame is wider than a real
G17 so the electronics fit.

## Parts

| STL / part | Filament | Notes |
|---|---|---|
| `frame_left.stl` | bright body colour | grip, mag well, Pico tray, USB heel cutout |
| `frame_right.stl` | bright body colour | mates with left; M2 screw tunnels |
| `slide.stl` | body or darker accent | OLED optic hump at rear |
| `trigger.stl` | body | pivot on 1.75 mm filament scrap |
| `magazine.stl` | body | holds 500 mAh LiPo + foam |
| `muzzle_collar.stl` | **orange** | toy tip over barrel |
| `oled_bezel.stl` | body or black | window over the OLED glass |

Preview the assembly in OpenSCAD with `part = "preview";` at the top of
`gun.scad`.

## Measure before a long print

Edit the named constants in `gun.scad` if your parts differ:

| Constant | Default (mm) | What to measure |
|---|---:|---|
| `oled_pcb_l` / `oled_pcb_w` | 28 / 28 | your 0.96" module PCB |
| `lipo_l` / `lipo_w` / `lipo_h` | 36 / 31 / 7 | cell + thin foam |
| `pico_h` | 12 | board + headers + solder blobs |
| `frame_width` | 42 | widen further if wires bind |

Print a 20 mm calibration cube and a quick `oled_bezel` first.

## Print settings

| Setting | Value |
|---|---|
| Material | **PETG** preferred (PLA OK for fit-check) |
| Layer height | 0.2 mm |
| Walls | 4 |
| Infill | 25% gyroid or grid |
| Supports | yes under trigger guard and Pico overhangs |
| Bed | clean; brim optional on the tall grip halves |

Orient:

- frame halves: mating face on the bed (flat split)
- slide: top deck on the bed
- magazine: base on the bed
- muzzle collar: flat end on the bed
- trigger: pivot ear on the bed

## Export STLs

```bash
cd projects/gun/cad
make
```

If [OpenSCAD](https://openscad.org/) is installed, that renders [`gun.scad`](gun.scad)
into `stl/`. If not, `make` runs [`export_stl.py`](export_stl.py) and writes
**approximate** box/cylinder meshes with the same pocket dimensions so you can
slice something immediately. Prefer OpenSCAD for the final print:

```bash
brew install --cask openscad   # macOS
cd projects/gun/cad && make    # re-export from gun.scad
```

Or open `gun.scad`, set `part = "frame_left";`, and use **File → Export → Export as STL**.

## Assembly

1. Solder and bench-test harnesses ([`../hardware/README.md`](../hardware/README.md)).
2. Seat the Pico in the left grip tray: USB toward the heel opening, antenna
   toward the beavertail (plastic keep-out only — no battery under the antenna).
3. Route OLED wires up into the slide optic pocket; clip the bezel over the glass.
4. Drop the IR nest into the muzzle cavity; LED faces forward in the barrel bore.
5. Glue or friction-fit the orange muzzle collar.
6. Place the DTS-644K in the trigger pocket; install the printed trigger; pin
   with a short length of 1.75 mm filament through the pivot holes.
7. Join left/right frames with M2×8 screws (8 points). Slide sits on the frame
   rails — friction or a dab of glue for the prototype.
8. Pad the LiPo with foam in the magazine; lead exits the top to the female JST
   hanging in the mag well. Insert mag to power on.

## Screws and hardware

- 8–12× M2×8 machine screws (or self-tapping into the bosses)
- 1× ~20 mm of 1.75 mm filament as trigger pivot
- Soft foam scrap for LiPo padding
- Optional: a drop of cyanoacrylate on the muzzle collar

## Fit checklist

- Micro-USB plug clears the heel without stressing the Pico
- BOOTSEL reachable through the left-side hole
- Mag inserts/removes without snagging the JST
- Trigger returns and the OLED title shows `H` at rest / `L` when held
- IR LED is recessed and points straight down the barrel

## Legal / safety notes (UK)

- Present and use as a **toy laser-tag marker**.
- Keep the **orange muzzle** fitted for public carry/play.
- Do not add realistic trademarks, serial numbers, or steel finishes that
  obscure the toy nature.
- Infrared only — never a laser diode.

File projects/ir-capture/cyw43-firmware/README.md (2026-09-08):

CYW43439 firmware copied from the Embassy project (Raspberry Pi / Cypress blobs):

https://github.com/embassy-rs/embassy/tree/main/cyw43-firmware

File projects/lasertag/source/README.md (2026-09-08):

# Source code

This directory will contain all executable project code.

## Intended structure

- `firmware/player/` — gun controls, IR transmission/reception, screen UI, and networking
- `shared/` — shot packet format, game events, IDs, and common test vectors
- `web/` — game server, browser UI, API, and persistent storage

The embedded targets are Raspberry Pi Pico 2 W boards. The first implementation
decision will be whether to use the Pico SDK (C/C++) or MicroPython; the
milestones in the documentation keep the protocol independent of that choice.

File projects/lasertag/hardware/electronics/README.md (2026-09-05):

# Electronics design placeholder

Future contents:

- KiCad project and PDF schematic;
- reviewed GPIO/pin allocation;
- measured power budget and battery-duration results;
- emitter driver current calculations and oscilloscope captures;
- receiver decoupling and connector pinout;
- PCB bill of materials and assembly notes.

Prototype wiring is not yet a production schematic. Validate component pinouts,
voltage limits, pulse current, polarity, and thermal behavior from the exact
manufacturer datasheets before assembly.

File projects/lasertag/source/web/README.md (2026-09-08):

# Web application

The web application will run on a small local server and provide:

- match setup, player/team assignment, and device status;
- a live scoreboard and per-player statistics;
- an operator interface for starting, pausing, and ending games;
- persistent players, matches, hits, and summary statistics;
- a device-facing API and real-time browser updates;
- export and backup of match history.

The initial deployment target is a Raspberry Pi on the same Wi-Fi network as
the Pico 2 W devices. A laptop can be used during development. The planned
default database is SQLite; internet hosting can be added later without making
the game dependent on an internet connection.

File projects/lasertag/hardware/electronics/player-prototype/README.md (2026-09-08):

# Player prototype schematic

Build this circuit twice, once for each player. The schematic is intentionally
limited to the parts in `docs/shopping-list.md` and does not cover the later
wearable harness or permanent PCB.

Complete player schematic

For a hole-by-hole assembly drawing and beginner instructions, use
[`breadboard-layout.md`](breadboard-layout.md):

Breadboard placement map

The SVG is the visual schematic. `pin-map.csv` records the GPIO allocation and
`connections.csv` is the machine-readable component netlist. The connection
schedule below is authoritative if a label in the drawing is difficult to
read.

## Fixed Pico pin map

| Function | Net | Pico GPIO | Physical pin |
|---|---|---:|---:|
| IR carrier output | `IR_TX` | GP0 | 1 |
| Trigger | `BTN_TRIGGER` | GP2 | 4 |
| Reload | `BTN_RELOAD` | GP3 | 5 |
| OLED data | `OLED_SDA` | GP4 | 6 |
| OLED clock | `OLED_SCL` | GP5 | 7 |
| Menu | `BTN_MENU` | GP6 | 9 |
| Front receiver | `RX_FRONT` | GP10 | 14 |
| Back receiver | `RX_BACK` | GP11 | 15 |
| Left receiver | `RX_LEFT` | GP12 | 16 |
| Right receiver | `RX_RIGHT` | GP13 | 17 |
| Regulated supply | `+3V3` | — | 36 |
| Ground | `GND` | — | 38 |

GP4 and GP5 are also connected to the PiCowbell's STEMMA QT socket. Nothing
else on the PiCowbell consumes those GPIOs. The generic four-pin OLED connects
to the PiCowbell's duplicate header or the breadboard with jumper wires; it
does not plug directly into the STEMMA QT socket.

On the Pico 2 W, GP23, GP24, GP25, and GP29 are used by the onboard CYW43439
Wi-Fi chip. Do not wire player I/O to those pins.

## Power and breadboard rails

1. Plug the Pico 2 W into the Adafruit 5906 PiCowbell socket, observing the USB-end
   orientation printed on the board.
2. With USB disconnected and the PiCowbell switch off, verify the LiPo's red
   wire reaches the `+` side of the JST-PH socket, then connect it.
3. Connect Pico physical pin 36 (`3V3 OUT`) to the breadboard positive rail.
4. Connect Pico physical pin 38 (`GND`) to the breadboard negative rail.
5. If a breadboard power rail is split in the middle, bridge both halves.
6. Do not connect `VBUS` or `VSYS` to the positive breadboard rail.

The PiCowbell handles USB/battery selection and LiPo charging through the Pico's
Micro-USB connector. Its slide switch controls Pico `3V3_EN`; it is not in
series with the battery. The 500 mAh battery uses the PiCowbell's default
500 mA charge setting, so do not cut the charge-rate jumper.

## IR transmitter

| From | Through | To |
|---|---|---|
| `+3V3` | R1 and R4, both 15 Ω 1 W, in series | D1 TSAL6200 anode |
| D1 cathode | direct | Q1 BC337-40 collector |
| Q1 emitter | direct | `GND` |
| GP0 / `IR_TX` | R2 and R5, both 220 Ω, in series | Q1 base |
| Q1 base | R3, 10 kΩ | `GND` |
| `+3V3` | C1, 4.7 µF and C2, 100 nF in parallel | `GND` |

Put C1 and C2 close to R1/D1. C1 is polarized: connect its positive lead to
`+3V3`. C2 is not polarized. The TSAL6200's long lead is the anode; its short
lead and flat package edge identify the cathode.

For the purchased Diotec BC337-40, the manufacturer drawing labels the leads
`C-B-E` from left to right in its illustrated flat-face orientation. TO-92
pinouts are not universal: match the actual part to the linked Diotec
datasheet before inserting it.

At a typical LED forward voltage of 1.35 V and an assumed saturated transistor
drop of 0.2 V, the 30 Ω series pair gives approximately:

`(3.3 V - 1.35 V - 0.2 V) / 30 Ω = 58 mA`

This is below the TSAL6200's 100 mA continuous rating as well as its pulse
rating, making the initial breadboard build tolerant of a stuck-high output.
The two 220 Ω base resistors give about `(3.3 V - 0.8 V) / 440 Ω = 5.7 mA`,
which is sufficient forced base drive at this collector current without
loading the Pico GPIO near its 12 mA drive setting. `IR_TX` should still emit
only bounded 38 kHz packet bursts.

The transmitter is deliberately powered from regulated `+3V3`, not `VSYS`.
`VSYS` rises when USB is attached and would make a low-value emitter resistor
produce inconsistent and potentially excessive current.

## Receiver zones

Build the following circuit four times. Keep each 100 nF capacitor physically
beside its receiver:

| Zone | GPIO/net | Receiver reference | Filter references |
|---|---|---|---|
| Front | GP10 / `RX_FRONT` | U2 | R10, C10, C11 |
| Back | GP11 / `RX_BACK` | U3 | R11, C12, C13 |
| Left | GP12 / `RX_LEFT` | U4 | R12, C14, C15 |
| Right | GP13 / `RX_RIGHT` | U5 | R13, C16, C17 |

For every zone:

1. Connect `+3V3` through its 100 Ω resistor to the receiver's local `VS`.
2. Connect 100 nF ceramic and 4.7 µF electrolytic capacitors in parallel from
   local `VS` to `GND`; electrolytic positive goes to `VS`.
3. Connect TSOP38238 pin 3 (`VS`) to local `VS`.
4. Connect pin 2 (`GND`) to common `GND`.
5. Connect pin 1 (`OUT`) directly to the zone GPIO.

With the TSOP38238's rounded lens facing you and leads downward, the pins are
`OUT-GND-VS` from left to right. Its output is active-low and contains an
internal pull-up; firmware may also enable the Pico's internal pull-up.

Do not share the 100 Ω resistor between zones. Separate filters reduce
transmitter and Wi-Fi supply noise reaching the receivers.

## OLED and buttons

Connect the OLED `VCC`, `GND`, `SDA`, and `SCL` pins to `+3V3`, `GND`, GP4,
and GP5 respectively. Confirm the labels on the purchased module because
four-pin OLED modules do not all use the same physical pin order.

Connect one side of each normally-open button to its assigned GPIO and the
other side to `GND`:

- trigger: GP2;
- reload: GP3;
- menu: GP6.

The controls are active-low and rely on Pico internal pull-ups. A four-leg
tactile switch has two permanently connected legs on each side; place it
across the breadboard centre gap so pressing it joins the two sides.

## Layout rules

- Keep the R1–D1–Q1–GND high-current loop short and away from receiver outputs.
- Give the transmitter its own short ground return to the common ground rail.
- Keep each receiver's 100 nF capacitor and ground lead as short as possible.
- Do not run receiver output jumpers alongside the IR LED current loop.
- Only join supplies through named nets; never join `+3V3`, `VSYS`, and `VBUS`.
- Use one complete breadboard and one PiCowbell per player.

## Measurement points

Every breadboard node is accessible without adding components. Reserve jumper
access at:

- `TP_IR_GATE`: GP0 before R2;
- `TP_IR_LED`: D1 cathode / Q1 collector;
- `TP_RX_FRONT`, `TP_RX_BACK`, `TP_RX_LEFT`, `TP_RX_RIGHT`: the four outputs;
- `TP_SDA` and `TP_SCL`: GP4 and GP5;
- `TP_3V3`, `TP_VSYS`, and at least two ground points.

Do not measure current by placing a multimeter directly across a supply. Pulse
current characterization requires a suitable current shunt and oscilloscope;
that is a later range-testing step, not required to assemble this safe starting
circuit.

## Inspection before applying power

1. Remove USB and disconnect the LiPo.
2. Check every polarized part: LiPo connector, TSAL6200, and 4.7 µF capacitors.
3. Check Q1 collector, base, and emitter against the Diotec package drawing.
4. Check there is no jumper between the positive and negative rails.
5. Check every TSOP38238 receives power through its own 100 Ω resistor.
6. Check the IR LED path includes R1, R4, and Q1; it must not connect to GP0
   directly.
7. Apply power with the PiCowbell switch off, then switch on and stop
   immediately if a component heats, smells, discolours, or the battery swells.

The circuit has no useful autonomous behaviour until firmware is loaded.
Initial firmware must leave GP0 low during boot and enforce bounded IR bursts.

## Source references

- [Raspberry Pi Pico 2 W datasheet](https://datasheets.raspberrypi.com/picow/pico-2-w-datasheet.pdf)
- [Raspberry Pi Pico pinout](https://datasheets.raspberrypi.com/pico/Pico-R3-A4-Pinout.pdf)
- [Adafruit Proto Doubler PiCowbell guide](https://cdn-learn.adafruit.com/downloads/pdf/adafruit-proto-doubler-picowbell.pdf)
- [Vishay TSAL6200 datasheet](https://www.vishay.com/docs/81010/tsal6200.pdf)
- [Vishay TSOP382/384 datasheet](https://www.vishay.com/docs/82491/tsop382.pdf)
- [Diotec BC337 series datasheet](https://diotec.com/request/datasheet/bc337.pdf)

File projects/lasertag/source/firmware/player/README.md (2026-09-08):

# Player firmware

One Raspberry Pi Pico 2 W controls all electronics for one player.

Planned responsibilities:

- read trigger, reload, and menu buttons;
- generate a 38 kHz modulated infrared shot packet;
- read four or more separately wired 38 kHz body receiver zones;
- validate and deduplicate hits while rejecting the player's own shots;
- enforce local ammunition, reload time, fire rate, and game state;
- show health, ammunition, score, and connection state on the OLED;
- exchange events and authoritative state with the game server over Wi-Fi;
- keep a short local event queue during temporary network loss.

Each receiver uses its own GPIO so firmware can preserve the hit zone. Receiver
cables and the gun controls converge on the same Pico 2 W, located either in the
gun or in a wearable enclosure. The IR LED must be driven through a transistor,
never directly from a GPIO pin.

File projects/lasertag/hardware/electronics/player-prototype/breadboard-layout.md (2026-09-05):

# Beginner breadboard assembly map

This guide builds **one player board**. Repeat it exactly on the second
breadboard for player two.

Breadboard placement map

Do not connect the battery or USB cable until the final inspection. Never move
a wire or component while power is connected.

## 1. How the breadboard works

Place the breadboard horizontally with column `1` at the left and column `63`
at the right:

```text
top power rails       red (+) and blue (-), connected sideways
upper terminal strip  rows a b c d e
centre trench         no electrical connection across it
lower terminal strip  rows f g h i j
bottom power rails    blue (-) and red (+), connected sideways
```

Within one numbered column, holes `a` through `e` are connected together.
Holes `f` through `j` in that column form a second, separate group. Adjacent
numbered columns are not connected. The long power rails connect sideways,
although some boards split each rail at the centre mark.

Coordinates such as `c20` mean row `c`, column `20`. The drawing is a
placement aid; the coordinate tables below remove any ambiguity.

## 2. Recognize and orient the parts

- **TSOP38238 receiver:** black rounded package with three legs. Hold the
  rounded lens toward you and the legs downward. Left to right is
  `OUT`, `GND`, `VS`.
- **TSAL6200 infrared LED:** looks like a clear or blue-grey 5 mm LED. The
  long leg is the positive **anode**. The short leg beside the flat rim is the
  negative **cathode**.
- **BC337-40 transistor:** small black part with one flat face and three legs.
  For the purchased Diotec part, flat face toward you and legs downward is
  `C`, `B`, `E` from left to right. Do not substitute a differently named
  transistor without checking its pin order.
- **4.7 uF electrolytic capacitor:** small cylinder. The stripe marks the
  negative leg. The unstriped/longer leg is positive.
- **100 nF ceramic capacitor:** small non-cylindrical part marked `104`. It
  has no positive or negative side.
- **Resistors:** they have no positive or negative side. Keep them separated
  in their labelled bags while assembling.
- **Push button:** four legs form two permanently joined pairs. It must bridge
  the breadboard centre trench as shown.
- **OLED:** use the labels printed beside its four pins. Do not infer the power
  pins from their left-to-right position.

## 3. Connect the power rails

Use red jumpers for `3V3` and black jumpers for `GND`.

1. PiCowbell/Pico physical pin `36`, labelled `3V3`, to the **top red rail** at
   column 1.
2. PiCowbell/Pico physical pin `38`, labelled `GND`, to the **top blue rail**
   at column 1.
3. Bridge the left and right halves of both top rails across the centre split.
   Even if your rails are continuous, these two short jumpers do no harm.
4. Join the top blue rail to the bottom blue rail at the far right.
5. Join the top red rail to the bottom red rail at the far right.

Never connect Pico `VBUS` or `VSYS` to a breadboard rail.

## 4. Fit the OLED

Insert its four pins into `a3`, `a4`, `a5`, and `a6`. The display body should
extend away from the centre trench.

Follow the words printed on the actual OLED:

| OLED label | Connect to |
|---|---|
| `VCC` | top red `3V3` rail |
| `GND` | top blue `GND` rail |
| `SCL` | PiCowbell/Pico GP5, physical pin 7 |
| `SDA` | PiCowbell/Pico GP4, physical pin 6 |

Because OLED pin order varies, the map labels these as `P1` to `P4` instead of
guessing which physical hole is VCC.

## 5. Fit the three buttons

Each button straddles the centre trench. Its four legs occupy:

| Button | Four holes | Signal jumper | Ground jumper |
|---|---|---|---|
| Trigger SW1 | `e8`, `e10`, `f8`, `f10` | GP2 physical pin 4 to `j8` | `j10` to bottom blue rail |
| Reload SW2 | `e13`, `e15`, `f13`, `f15` | GP3 physical pin 5 to `j13` | `j15` to bottom blue rail |
| Menu SW3 | `e17`, `e19`, `f17`, `f19` | GP6 physical pin 9 to `j17` | `j19` to bottom blue rail |

The signal and ground must go to opposite internally connected sides. If a
button appears permanently pressed later, rotate it 90 degrees and place it
again across the trench.

## 6. Build the four receiver zones

Insert every receiver with its rounded lens facing the **bottom edge** of the
breadboard. Its pins then run left-to-right as `OUT`, `GND`, `VS`.

| Zone | Receiver pins `OUT,GND,VS` | 100 ohm from red rail to | 100 nF capacitor | 4.7 uF capacitor | GPIO jumper |
|---|---|---|---|---|---|
| Front U2 | `c20,c21,c22` | `a22` | `d22` to `d23` | `e22` (+) to `e24` (-) | `e20` to GP10 pin 14 |
| Back U3 | `c29,c30,c31` | `a31` | `d31` to `d32` | `e31` (+) to `e33` (-) | `e29` to GP11 pin 15 |
| Left U4 | `c38,c39,c40` | `a40` | `d40` to `d41` | `e40` (+) to `e42` (-) | `e38` to GP12 pin 16 |
| Right U5 | `c47,c48,c49` | `a49` | `d49` to `d50` | `e49` (+) to `e51` (-) | `e47` to GP13 pin 17 |

For each row in the table:

1. Put one leg of its 100 ohm resistor in the top red rail and the other in the
   listed `a` hole.
2. Put the 100 nF capacitor in its two listed holes.
3. Put the electrolytic capacitor in its two listed holes, with positive on
   the receiver `VS` column and striped negative on the other column.
4. Join the receiver `GND` column to the top blue rail with black wire.
5. Join both capacitor ground columns to the top blue rail with black wire.
6. Add the blue signal jumper from `OUT` to the listed Pico pin.

Do not replace the three separate ground jumpers with links between columns:
joining adjacent columns could short a receiver supply to ground.

## 7. Build the IR transmitter

Place the Diotec BC337-40 at `h55`, `h56`, `h57`, with its **flat face toward
the bottom edge**. This makes:

- `h55` = collector `C`;
- `h56` = base `B`;
- `h57` = emitter `E`.

Then place:

| Part | First end | Second end | Orientation |
|---|---|---|---|
| R1, 15 ohm 1 W | bottom red rail column 45 | `j45` | either way |
| R4, 15 ohm 1 W | `i45` | `i52` | either way |
| D1, TSAL6200 | long anode in `h52` | short/flat-side cathode in `h55` | polarity matters |
| R2, 220 ohm | `f63` | `f59` | either way |
| R5, 220 ohm | `g59` | `g54` | either way |
| R3, 10 kohm | `j56` | bottom blue rail column 56 | either way |
| C1, 4.7 uF | bottom red rail column 47 | bottom blue rail column 47 | positive to red |
| C2, 100 nF | bottom red rail column 50 | bottom blue rail column 50 | either way |

Finish with:

1. GP0, physical pin 1, to `j63` with a blue jumper.
2. Join `i54` to `i56` with a short insulated jumper. This connects the end of
   R5 to the transistor base.
3. `j57` to the bottom blue ground rail with black wire.

R1 and R4 are electrically in series because holes `i45` and `j45` are joined
inside the breadboard. R2 and R5 are similarly joined through column 59. Do
not omit either resistor or the `i54`-to-`i56` jumper.

## 8. PiCowbell signal checklist

These are the only signal jumpers between the PiCowbell/Pico and breadboard:

| Pico physical pin | Printed GPIO | Breadboard destination |
|---:|---|---|
| 1 | GP0 | `j63`, IR transmitter |
| 4 | GP2 | `j8`, trigger |
| 5 | GP3 | `j13`, reload |
| 6 | GP4 | OLED pin labelled `SDA` |
| 7 | GP5 | OLED pin labelled `SCL` |
| 9 | GP6 | `j17`, menu |
| 14 | GP10 | `e20`, front receiver |
| 15 | GP11 | `e29`, back receiver |
| 16 | GP12 | `e38`, left receiver |
| 17 | GP13 | `e47`, right receiver |
| 36 | 3V3 | top red rail |
| 38 | GND | top blue rail |

Use the labels printed on the PiCowbell. Do not count pins from memory.

## 9. Inspect before connecting power

With USB and battery still disconnected:

1. Check every part against the map, one column at a time from left to right.
2. Check every striped electrolytic side goes to a blue ground rail.
3. Check D1's long leg is at `h52` and short/flat side is at `h55`.
4. Check Q1's flat face points toward the bottom edge.
5. Check all four receivers' rounded lenses point toward the bottom edge.
6. Check no component or wire joins a red rail directly to a blue rail.
7. Check neither `VSYS` nor `VBUS` is connected to the breadboard.
8. Ask another person to repeat the visual check if possible.

Only after inspection:

1. Put the PiCowbell switch in the off position.
2. Verify the LiPo red wire aligns with `+` at the PiCowbell socket.
3. Connect the LiPo.
4. Switch on for five seconds while watching, smelling, and carefully checking
   for heat without touching bare conductors.
5. Switch off immediately if anything heats, smells, discolours, or if the
   battery changes shape.

Nothing useful will appear on the OLED and the IR circuit will remain off until
firmware is installed. That is expected.

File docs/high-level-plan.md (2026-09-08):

# High-level project plan

## 1. Goal and first playable version

Build a reusable laser-tag platform for `N` players, starting with a complete
two-player prototype. The game must continue to register shots on a local
network without internet access.

The first playable version consists of:

- two handheld guns;
- one Raspberry Pi Pico 2 W controller per player;
- four receiver zones per player (front, back, left shoulder, right shoulder);
- a 128×64 OLED on each gun showing health, ammunition, score, and status;
- a local server with an operator dashboard, live scoreboard, and persistent
  match history;
- placeholders for printable gun shells, receiver pods, and wearable mounts.

The word “laser” is conventional: shots use modulated 940 nm infrared LEDs.
Laser diodes are unnecessary and create avoidable eye-safety risk.

## 2. System architecture

### Per-player hardware

Each player has one Raspberry Pi Pico 2 W. It:

- reads trigger, reload, and menu buttons;
- emits a short encoded shot through a 940 nm IR LED at a 38 kHz carrier;
- connects to at least four separately wired TSOP38238 receiver modules;
- decodes shots, rejects its own player ID, and records the body zone;
- controls the OLED;
- exchanges hit events and authoritative game state with the server over Wi-Fi;
- provides future connection points for vibration, light, or sound feedback.

Each receiver has a dedicated GPIO, preserving zone information while avoiding
a microcontroller in every sensor pod. Receiver and control cables converge on
the Pico 2 W, which can be mounted in the gun or in a wearable enclosure. Add
zones subject to GPIO, cabling, power, and interrupt-handling limits.

### Game server

The server runs on a Raspberry Pi or development computer and is authoritative
for match state. It provides:

- an HTTP API for setup and history;
- a WebSocket or server-sent-event stream for live updates;
- device presence/health monitoring;
- scoring and game-rule enforcement;
- an SQLite database;
- a responsive browser interface for phones, tablets, and computers.

The preferred first network topology is an ordinary private Wi-Fi network.
Later, the server can provide a dedicated access point for portable play. Core
gameplay must not depend on cloud services.

### Event flow

1. The operator assigns stable device IDs to players and starts a match.
2. The server distributes the match configuration to each player controller.
3. A gun checks local fire-rate/ammunition rules and emits an IR packet.
4. One or more body sensors receive it; the target Pico validates and
   deduplicates it.
5. The target Pico submits
   `shot ID + shooter + victim + zone + local sequence/time`.
6. The server applies authoritative rules, persists the event, and broadcasts
   updated state.
7. The victim and shooter screens are refreshed.

Devices should use monotonically increasing sequence numbers and bounded
queues. This makes retries idempotent and tolerates short Wi-Fi interruptions.

## 3. Protocol outline

### Infrared

Start with a compact binary packet containing:

- protocol version;
- shooter/device ID;
- team ID;
- shot sequence number;
- weapon/damage type;
- checksum or CRC.

Use a 38 kHz carrier compatible with the TSOP38238. Define timings and publish
test vectors before optimizing range. A packet must be validated completely
before it becomes a hit. The player controller must collapse the same packet seen by
adjacent body zones into one hit while preserving the strongest/first zone.

### Network

Use versioned JSON during development for observability. Define messages for
registration, heartbeat, configuration, shot/hit event, acknowledgement, state
snapshot, and error. Move to a compact binary encoding only if measurement
shows it is needed.

Security for the prototype: private Wi-Fi, unique device credentials, server
validation of IDs and match membership, and no unauthenticated admin controls.
Internet exposure requires TLS, real user authentication, secret management,
updates, and a separate threat review.

## 4. Hardware design checkpoints

Before soldering permanent assemblies:

- measure IR LED current and transistor switching on a breadboard;
- verify reliable decoding at the desired indoor range and angles;
- test receiver behavior in sunlight and under LED/fluorescent lighting;
- verify that simultaneous receiver-zone signals do not overwhelm firmware;
- measure peak and average current for each node;
- run a full battery-duration test;
- verify USB charging, low-voltage cutoff, connector polarity, and enclosure
  protection for the LiPo battery;
- confirm that Wi-Fi loss cannot create extra hits or corrupt match history.

The IR emitter requires a transistor driver and current-limiting resistor.
Never power it directly from a Pico GPIO. Every receiver should have local
decoupling close to its supply pins. Add reverse-polarity and strain protection
before moving from bench prototypes to wearable hardware.

## 5. Software decomposition

### Firmware

- hardware abstraction for pins, buttons, OLED, and IR;
- deterministic shot encoder and decoder;
- local gun/player state machine;
- Wi-Fi provisioning, reconnect, heartbeat, and event queue;
- over-the-air or USB update path;
- serial diagnostics and self-test.

### Server and web UI

- device registry and player/team assignment;
- configurable game modes and rule engine;
- match lifecycle and authoritative event processor;
- real-time operator dashboard and public scoreboard;
- SQLite schema and migrations;
- match/player history, summaries, export, and backup;
- simulator for developing without complete hardware.

### Testing

- shared protocol vectors used by encoder and decoder tests;
- simulated devices and deterministic match scenarios;
- firmware tests for packet validation and deduplication;
- API, database migration, and scoring tests;
- hardware-in-the-loop range, ambient-light, latency, and endurance tests.

## 6. Delivery milestones

### Milestone 0 — decisions and bench setup

- choose Pico SDK/C++ or MicroPython after a timing proof of concept;
- assign pin maps and stable IDs;
- write protocol version 1 and electrical schematics;
- inventory and smoke-test purchased parts.

Exit: both Pico 2 W boards can connect to Wi-Fi, display status, and exchange a
test event with a development server.

### Milestone 1 — one-way IR link

- build one transistor-driven emitter and one receiver;
- encode/decode IDs with checksum;
- characterize indoor range and false-positive rate.

Exit: at least 100 consecutive valid shots at target range with no duplicate
hits and no unsafe component temperature/current.

### Milestone 2 — one complete player unit

- finish gun controls and display;
- connect four wearable zones to the same Pico 2 W;
- implement zone deduplication and local feedback;
- test battery life and disconnect handling.

Exit: the complete unit transmits valid packets and detects test packets on all
four body zones.

### Milestone 3 — two-player game

- assemble the second one-Pico player unit;
- implement match lifecycle, score rules, and live dashboard;
- persist complete match history in SQLite;
- test crossed shots, rapid fire, retries, and reboots.

Exit: repeatable two-player matches with correct totals after all devices and
the server reconnect.

### Milestone 4 — enclosures and field hardening

- design printable gun, screen, receiver-pod, controller, and battery enclosures;
- add connectors, cable strain relief, battery padding, and protected access to
  the power button and USB charging port;
- perform drop, snag, heat, endurance, and eye-safety reviews.

Exit: wearable prototypes survive normal play without exposed conductors,
sharp edges, loose batteries, or pointing hazards.

### Milestone 5 — scale and deploy

- load-test simulated `N`-player games;
- add portable access-point deployment and automated server backups;
- document assembly, provisioning, calibration, and repair;
- consider optional internet synchronization only after local operation is
  reliable.

## 7. Decisions intentionally deferred

- firmware language and RTOS choice;
- final gun optics and practical maximum range;
- final battery capacity and any future custom charging PCB;
- PCB design;
- enclosure ergonomics and printer/material choice;
- exact game modes, sound, lighting, haptics, and cloud hosting.

These are deferred until the breadboard measurements establish timing, current,
thermal, range, and usability requirements.

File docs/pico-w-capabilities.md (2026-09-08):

# What the Raspberry Pi Pico 2 W can do

This project uses the **Raspberry Pi Pico 2 W**. It is the wireless Pico 2:
an RP2350 microcontroller with an Infineon CYW43439 for 2.4 GHz Wi-Fi and
Bluetooth. Header pins must be fitted (or bought pre-soldered) to plug into
the PiCowbell. A Pico 2 without the W has no radio.

The most important distinction is:

> A Pico 2 W is a microcontroller, not a small Linux computer.

It is designed to start one embedded program quickly, interact directly with
buttons, sensors and LEDs, and keep doing that job predictably. A Raspberry Pi
Zero, 4 or 5 is a general-purpose computer designed to run Linux, processes,
desktop applications and large files.

## Short answer

The Pico 2 W:

- does **not** practically run Raspberry Pi OS or ordinary Linux;
- runs a firmware program directly on its RP2350 microcontroller;
- has two Arm Cortex-M33 cores (or two RISC-V Hazard3 cores), typically at
  up to 150 MHz; this project uses the Arm cores;
- has 520 KiB of volatile working memory (SRAM);
- has 4 MiB of persistent flash shared by firmware and saved data;
- has 2.4 GHz Wi-Fi and Bluetooth 5.2;
- can read buttons and sensors and precisely control outputs;
- can run C/C++, MicroPython, Arduino-style code, Rust, or a small RTOS;
- cannot replace the game server, database, or rich web dashboard.

That is ample for one laser-tag player controller.

## Does it run Linux?

Not in the normal or useful sense.

The RP2350 has only 520 KiB of RAM and no memory-management unit (MMU) of the
kind a desktop Linux kernel expects. It has no built-in disk, display
controller, HDMI, Ethernet, keyboard interface or large external RAM. A normal
Linux system expects vastly more memory and usually an MMU for virtual memory
and process isolation.

Experimental Unix-like systems or emulators can be made for very small
microcontrollers, but they are demonstrations rather than a sensible basis for
this project. They would consume resources while making real-time IR handling
less reliable.

The Pico can instead run:

- **bare-metal firmware:** one program directly controls the hardware;
- **MicroPython:** a compact Python interpreter and your Python scripts;
- **a real-time operating system:** for example FreeRTOS, providing tasks,
  queues and timers without becoming a desktop operating system;
- **a custom scheduler/event loop:** often enough for a project this size.

The web server and SQLite database belong on a laptop, desktop computer or
Linux-capable Raspberry Pi. The Pico 2 W communicates with that server over
Wi-Fi.

## What happens when it powers on?

1. Permanent code in the RP2350's internal boot ROM runs.
2. Normally it finds the firmware stored in the external flash chip.
3. The firmware initializes RAM, clocks and peripherals.
4. Its entry function starts and normally continues until power is removed,
   the watchdog resets it, or firmware requests a restart.

There is no login screen and no shell unless the firmware deliberately
provides one. There are no independent applications being launched by an
operating system. The loaded firmware owns the machine.

Holding `BOOTSEL` while connecting USB starts the ROM USB bootloader. The Pico
appears to the computer as a drive named `RP2350`; copying a UF2 firmware file
to it reprograms flash and reboots the board. The apparent USB drive is a
programming interface, not a normal 4 MiB disk.

With MicroPython installed, a computer can also open a USB serial REPL. The
REPL is an interactive Python prompt supplied by MicroPython, not Linux.

## Processor

The RP2350 contains:

- two Arm Cortex-M33 cores, normally clocked at up to 150 MHz, with a
  single-precision floating-point unit (or two Hazard3 RISC-V cores instead;
  this project uses Arm);
- hardware integer divider and interpolator blocks;
- 16 DMA channels for moving data without constant CPU involvement;
- interrupt, timer and watchdog hardware;
- Arm TrustZone, OTP, and optional signed boot;
- a 16 KiB cache in front of execute-in-place flash.

Both cores can run simultaneously, but using two cores requires explicit
coordination. They share RAM, flash and peripherals. Two cores do not turn the
board into a desktop computer and do not automatically make every program
twice as fast.

For this project, one core would already be sufficient. Hardware PWM or PIO
can produce the 38 kHz IR carrier while the CPU handles buttons, received
packets, the OLED and network events.

## Memory: RAM versus persistent flash

### 520 KiB SRAM: temporary working memory

SRAM holds values that change while the program runs:

- variables and object state;
- function call stacks;
- network packet buffers;
- the MicroPython heap, when MicroPython is used;
- queues of pending hits or messages;
- an OLED framebuffer;
- code copied to RAM for time-critical work.

SRAM loses all contents when power is removed or the Pico resets. It is shared
by both CPU cores, the Wi-Fi/network software and the application.

`520 KiB` is 532,480 bytes. The application cannot normally use all of it:
firmware runtime state, stacks, drivers and network buffers take a portion.
MicroPython itself consumes substantially more RAM than a small compiled C
program, and the exact free heap changes between firmware builds.

The 16 KiB flash cache is not additional general-purpose RAM. It automatically
speeds access to code and read-only data held in flash.

### 4 MiB QSPI flash: persistent memory

The Pico 2 W board has a separate 4 MiB flash chip. Its contents remain after
power is removed. It normally contains:

- the executable firmware or MicroPython interpreter;
- constants such as fonts, lookup tables and default configuration;
- MicroPython files, if using its filesystem;
- any explicitly reserved application-data area.

The RP2350 itself has no large internal user flash for application code. It
reads code from the board's external flash through QSPI and can execute that
code in place, known as XIP. A small OTP region exists for keys and factory
data; it is not general application storage.

`4 MiB` is 4,194,304 bytes, but not all of it is available for saved data.
Firmware occupies part of it. A MicroPython build also reserves space for the
interpreter and exposes the remaining portion as a small filesystem. Exact
free space depends on the specific firmware version and partition layout.

In a C/C++ program, there is no filesystem automatically. The program may:

- reserve fixed flash sectors for configuration;
- use a small embedded filesystem such as LittleFS;
- add an external EEPROM, flash chip or microSD card;
- send durable records to the game server instead.

### Flash is not RAM and not an unlimited-write disk

Flash can be read frequently, but changing it is more complicated:

- the common erase unit is a 4 KiB sector;
- programming is performed in aligned pages, commonly 256 bytes;
- an erase changes a whole sector back to its blank state;
- erase/program operations temporarily prevent ordinary XIP flash access;
- flash has finite erase endurance;
- power loss during an update can corrupt an incompletely written record.

Do not rewrite a score counter to the same flash sector after every shot.
Buffer events in RAM, write infrequently, use redundant records or wear
levelling, and let the server provide authoritative long-term persistence.

Appropriate Pico flash data for this project includes:

- device/player ID;
- Wi-Fi provisioning information;
- calibration and hardware revision;
- last acknowledged network sequence number;
- small batches of events awaiting server delivery;
- firmware settings that change rarely.

Complete match history and statistics belong in the server's SQLite database.

### Other storage-related facts

- There is no built-in EEPROM.
- There is no built-in SD-card slot.
- There is no battery-backed storage.
- The boot ROM is permanent factory-programmed code, not application storage.
- The wireless chip's internal memory is managed by its driver and is not
  general application RAM.
- External storage can be added over SPI or I2C if genuinely needed.

## What can fit in 4 MiB?

Exact sizes depend on language, libraries and compiler options, but these are
realistic categories.

Comfortable:

- the complete laser-tag player firmware;
- IR encoding/decoding and test vectors;
- OLED fonts, icons and menus;
- Wi-Fi networking and a compact application protocol;
- configuration and a bounded offline event queue;
- diagnostics and a USB command interface;
- a small HTTP status/configuration page.

Possible but increasingly constrained:

- MicroPython plus several application modules;
- TLS networking, depending on library configuration and certificate sizes;
- a larger set of fonts, sounds or compressed assets;
- over-the-air updates, especially if trying to keep both old and new firmware
  images at once;
- Bluetooth and Wi-Fi features together with large application buffers.

Poor fits:

- a Linux distribution;
- SQLite and a durable match-history database;
- a modern browser or JavaScript application runtime;
- images, music or video collections;
- large machine-learning models;
- a rich web dashboard with extensive static assets;
- unbounded logs.

As a scale example, the 128 by 64 monochrome OLED needs only 1,024 bytes for a
full one-bit framebuffer. A compact hit event might be tens of bytes. The
limitation is therefore not basic laser-tag state; it is large runtimes,
network buffers, rich media and durable bulk storage.

## Programming choices

### C/C++ with the official Pico SDK

The source code is compiled on a normal computer into a UF2 firmware image.
The Pico runs the resulting machine code directly.

Advantages:

- best control over timing and hardware;
- smallest and most predictable RAM usage;
- direct access to PWM, PIO, interrupts, DMA and both cores;
- suitable for production firmware.

Costs:

- longer build/debug cycle;
- memory ownership and concurrency require care;
- more opportunities for low-level bugs.

### MicroPython

The Pico first runs MicroPython firmware. Your `.py` files are then interpreted
on the board.

Advantages:

- simple, interactive development through the REPL;
- readable code and quick experiments;
- suitable for proving OLED, button, receiver and network behavior;
- hardware PWM and PIO remain accessible.

Costs:

- less free RAM and flash;
- slower general Python execution;
- garbage collection can introduce timing pauses;
- some low-level libraries and features differ from the C SDK.

Time-critical IR carrier generation should still use hardware PWM or PIO, not
a Python loop toggling a pin.

### Other options

- **Arduino-Pico:** familiar Arduino APIs on top of RP2350 support.
- **Rust:** strong compile-time safety with community RP2350 libraries
  (`embassy-rp` with the `rp235xa` feature for Pico 2 W).
- **CircuitPython:** beginner-friendly Python variant, but generally uses more
  flash/RAM and has different library trade-offs.
- **FreeRTOS:** task scheduling for C/C++ firmware when a deliberate RTOS
  architecture is useful.

Official Raspberry Pi support is strongest for the C/C++ SDK and MicroPython.

## Input and output hardware

The Pico 2 W exposes 26 multifunction 3.3 V GPIO pins:

- 23 are digital-only;
- three exposed pins can also be analogue inputs;
- digital pins can act as input, output, interrupt, PWM or peripheral signals;
- pin functions can include UART, SPI and I2C.

The RP2350 provides:

- two UART controllers;
- two SPI controllers;
- two I2C controllers;
- 24 PWM channels across twelve slices;
- a 12-bit ADC rated up to 500 ksps;
- one internal temperature-sensor ADC input;
- USB 1.1 device or host hardware;
- twelve PIO state machines across three PIO blocks.

PIO is a distinctive RP2350 feature: tiny deterministic state machines execute
short programs independently of the CPU. They can generate or receive precise
digital waveforms. This is useful for custom protocols and could handle the IR
carrier or packet timing, although ordinary PWM is sufficient for the initial
38 kHz transmitter.

### Electrical limits

GPIO is **3.3 V logic and is not 5 V tolerant**. A GPIO is a signal pin, not a
power supply:

- do not connect a 5 V output directly to it;
- do not power motors, buzzers or high-current LEDs from it;
- use a transistor or driver for the IR LED;
- connect all interacting circuits to a common ground;
- configure unused or boot-sensitive outputs to a safe state.

The current schematic follows these rules by using the BC337-40 transistor and
leaving the IR gate low until firmware deliberately sends a shot.

## Wi-Fi and Bluetooth

The Pico 2 W includes an Infineon CYW43439 radio connected to the RP2350:

- Wi-Fi 4 / IEEE 802.11b/g/n;
- single-band 2.4 GHz only;
- WPA3 capability;
- station mode for joining an existing network;
- SoftAP mode for creating a small access point, officially up to four clients;
- Bluetooth 5.2;
- Bluetooth Low Energy central and peripheral roles;
- Bluetooth Classic support.

The actual features available depend on the firmware, SDK and libraries being
used. Wi-Fi and Bluetooth consume RAM, flash and power, and radio traffic is
not deterministic.

The Pico 2 W can run TCP, UDP, DNS, DHCP, HTTP, WebSocket-like application
protocols and MQTT when suitable libraries are included. TLS is possible but
uses noticeably more memory and processing time.

For laser tag, each Pico should join a private 2.4 GHz network as a client.
Real-time hit detection remains local; Wi-Fi carries events and game state.
Gameplay should tolerate packets being delayed, duplicated or temporarily
lost.

Keep metal, batteries and dense wiring away from the onboard antenna end of
the Pico 2 W. Poor physical placement can reduce range.

## Timing and real-time behavior

A microcontroller is good at predictable hardware timing, but network traffic,
interpreters and flash writes can cause delays. The design should separate
responsibilities:

- PWM/PIO generates the exact 38 kHz carrier;
- GPIO interrupts capture receiver transitions;
- timers enforce packet timing and fire rate;
- the foreground loop updates the display and game state;
- networking runs asynchronously and uses queues;
- flash writes happen outside time-critical receive windows.

The watchdog can reset the firmware if it hangs. On restart, RAM is lost, so
important sequence/configuration data must be recoverable from flash or the
server.

## Clock and time

The RP2350 contains timer and real-time-clock hardware, but the Pico 2 W has no
battery-backed clock. It does not know civil date/time after complete power
loss unless it receives the time from a server or an external RTC.

For IR packets and local event ordering, use monotonic timers that measure time
since boot. Use the game server for authoritative wall-clock timestamps.

## Can it host a web server?

Yes, but only a small embedded one.

It can serve a compact setup or status page and handle a few connections. It
is not suited to storing match history, rendering a rich dashboard, performing
large database queries or serving many simultaneous users.

In this project:

- Pico 2 W: player hardware, immediate rules, display, IR and network client;
- external server: match authority, web UI, user access and SQLite history.

This division keeps the player responsive even when the server or Wi-Fi is
temporarily unavailable.

## Updates and recovery

USB UF2 installation is the simplest and most reliable update path during
development. It can always be reached through the ROM `BOOTSEL` mechanism even
if application firmware is broken.

Network/over-the-air updates are possible. 4 MiB leaves more room than the
older 2 MiB Pico W, but an updater must still authenticate the image, survive
power loss and avoid overwriting its currently executing flash code. OTA
should be added only after the basic firmware is stable.

SWD pads provide low-level programming and debugging with an external debug
probe. They are useful for difficult firmware faults but not required for the
initial prototype.

## Security limitations

RP2350 is stronger than RP2040 (TrustZone, optional signed boot, OTP key
storage), but a player tag is still a physically accessible device:

- application code and credentials usually reside in external flash;
- signed boot and flash protection are optional and must be designed in;
- physical debug/access can expose secrets if those features are unused;
- all firmware code shares one address space without desktop-style process
  isolation.

Use a private Wi-Fi network, per-device credentials, server-side validation and
short-lived/revocable secrets. Do not treat a secret stored on a physically
accessible player unit as impossible to extract.

## Recommended role in this project

One Pico 2 W can comfortably:

- read all four receiver zones independently;
- generate encoded IR shots;
- read trigger, reload and menu controls;
- maintain health, ammunition and short-term game state;
- draw the OLED interface;
- connect to Wi-Fi;
- queue events during a brief disconnection;
- store a small amount of configuration persistently;
- recover safely after resets.

It should not:

- own the only copy of match history;
- run the main SQLite database;
- host the full operator dashboard;
- depend on Wi-Fi for immediate hit detection;
- log every low-level transition permanently to flash;
- directly drive the high-current IR LED.

## Official references

- [Raspberry Pi Pico 2 W datasheet](https://datasheets.raspberrypi.com/picow/pico-2-w-datasheet.pdf)
- [RP2350 datasheet](https://datasheets.raspberrypi.com/rp2350/rp2350-datasheet.pdf)
- [Raspberry Pi microcontroller documentation](https://www.raspberrypi.com/documentation/microcontrollers/)
- [MicroPython on Pico-series boards](https://www.raspberrypi.com/documentation/microcontrollers/micropython.html)
- [Pico C/C++ SDK](https://www.raspberrypi.com/documentation/microcontrollers/c_sdk.html)
- [Pico SDK networking libraries](https://www.raspberrypi.com/documentation/pico-sdk/networking.html)

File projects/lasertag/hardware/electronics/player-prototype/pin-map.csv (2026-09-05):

function | net | pico_gpio | pico_physical_pin | direction | active_level | notes
IR transmitter | IR_TX | GP0 | 1 | output | high | 38 kHz carrier; PWM slice 0 channel A or PIO
Trigger button | BTN_TRIGGER | GP2 | 4 | input | low | Switch to GND; enable internal pull-up
Reload button | BTN_RELOAD | GP3 | 5 | input | low | Switch to GND; enable internal pull-up
OLED data | OLED_SDA | GP4 | 6 | bidirectional | n/a | I2C0 SDA; also routed to PiCowbell STEMMA QT
OLED clock | OLED_SCL | GP5 | 7 | output | n/a | I2C0 SCL; also routed to PiCowbell STEMMA QT
Menu button | BTN_MENU | GP6 | 9 | input | low | Switch to GND; enable internal pull-up
Front receiver | RX_FRONT | GP10 | 14 | input | low | TSOP38238 output; idle high
Back receiver | RX_BACK | GP11 | 15 | input | low | TSOP38238 output; idle high
Left receiver | RX_LEFT | GP12 | 16 | input | low | TSOP38238 output; idle high
Right receiver | RX_RIGHT | GP13 | 17 | input | low | TSOP38238 output; idle high
Logic and peripheral power | +3V3 | n/a | 36 | power | n/a | Feed breadboard positive rail from regulated 3.3 V only
Common return | GND | n/a | 38 | power | n/a | Feed breadboard ground rail; all grounds common
Battery/system input | VSYS | n/a | 39 | power | n/a | Managed by PiCowbell; do not use for the IR LED prototype
USB input | VBUS | n/a | 40 | power | n/a | Managed by Pico/PiCowbell; do not connect to breadboard positive rail

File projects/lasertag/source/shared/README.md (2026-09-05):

# Shared protocol

This directory will define the versioned contracts used by firmware and the
server:

- player, team, device, match, and receiver-zone identifiers;
- infrared shot packet fields and checksum;
- network event schemas;
- sequence numbers and duplicate-event rules;
- protocol compatibility and test vectors.

The infrared packet should contain only the data needed to validate a shot,
such as protocol version, shooter/team ID, shot sequence, and checksum. The
server remains authoritative for scoring and persistence.

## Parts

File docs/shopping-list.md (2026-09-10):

# Shopping list: working two-player prototype

This is the complete hardware list for a functional, rechargeable, bench-top
prototype with:

- one Raspberry Pi Pico 2 W per player;
- one IR transmitter and four independent IR receiver zones per player;
- one OLED and three controls per player;
- Wi-Fi communication with a web server running on an existing computer;
- solderless construction on two breadboards.

The prototype is not yet wearable or impact-resistant. Enclosures, body wiring,
sound, permanent connectors, dedicated server hardware, and fabrication tools
are deliberately deferred until the core design works.

Prices and stock change frequently. Links and approximate prices were checked
on 5 September 2026. Rapid prices may be displayed without VAT.

## Buy this list

| Done | Qty | Item | Exact product and UK shop | Purpose |
|:---:|---:|---|---|---|
| ✅ | 2 | Wi-Fi microcontroller | [Raspberry Pi Pico 2 W — select the version **with headers** if you want to skip soldering, The Pi Hut](https://thepihut.com/products/raspberry-pi-pico-2-w) | RP2350 with onboard 2.4 GHz Wi-Fi; one per player; headers required for the PiCowbell |
| ✅ | 2 | Rechargeable power/prototyping board | [Adafruit Proto Doubler PiCowbell for Pico and Pico W (£7.30 each), The Pi Hut](https://thepihut.com/products/adafruit-proto-doubler-picowbell-for-pico-and-pico-w) | No-solder Pico socket, LiPo charger, power switch, and accessible GPIO |
| ✅ | 2 | Rechargeable battery | [500 mAh 3.7 V LiPo with JST-PH connector (£6 each), The Pi Hut](https://thepihut.com/products/500mah-3-7v-lipo-battery) | One per player; plugs directly into the PiCowbell |
| ✅ | 2 | Player display | [0.96-inch 128×64 I²C SSD1306 OLED (£4 each), The Pi Hut](https://thepihut.com/products/0-96-oled-display-module-128x64) | Health, ammunition, score, and connection status |
| ✅ | 8 | IR receiver | [Vishay TSOP38238 38 kHz receiver (£1 each), The Pi Hut](https://thepihut.com/products/ir-infrared-receiver-tsop38238) | Four separately wired hit zones per player |
| ✅ | 10 | IR emitter | [Vishay TSAL6200 940 nm LED, Rapid code 49-4513](https://www.rapidonline.com/vishay-tsal6200-5mm-940nm-ir-transmitter-diode-49-4513) | Two used; Rapid's price break begins at ten |
| ✅ | 50 | IR-driver transistor | [Diotec BC337-40, Rapid code 50-3113](https://www.rapidonline.com/bc337-40-diotec-bipolar-npn-transistor-45v-50-3113) | Two used; Rapid's minimum order is fifty |
| ✅ | 1 pack | 100 Ω resistors | [Royal Ohm CFR0W4J0101KIT, pack of 100, Rapid code 62-0346](https://www.rapidonline.com/royal-ohm-cfr0w4j0101kit-100r-carbon-film-resistor-0-25w-pack-of-100-62-0346) | One supply-filter resistor per IR receiver |
| ✅ | 1 pack | 220 Ω resistors | [Royal Ohm CFR0W4J0221KIT, pack of 100, Rapid code 62-0354](https://www.rapidonline.com/royal-ohm-cfr0w4j0221kit-220r-carbon-film-resistor-0-25w-pack-of-100-62-0354) | Two in series per BC337 base |
| ✅ | 1 pack | 10 kΩ resistors | [Royal Ohm CFR0W4J0103KIT, pack of 100, Rapid code 62-0394](https://www.rapidonline.com/royal-ohm-cfr0w4j0103kit-10k-carbon-film-resistor-0-25w-pack-of-100-62-0394) | Transistor pull-downs and button inputs |
| ✅ | 10 | 15 Ω, 1 W resistors | [Royal Ohm MFF1WFF0150A10, Rapid code 62-8705](https://www.rapidonline.com/royal-ohm-mff1wff0150a10-15r-1-1w-flame-proof-metal-film-resistor-62-8705) | Two in series per IR LED give a safe 30 Ω starting value |
| ✅ | 10 | 100 nF ceramic capacitors | [Suntan TS170R2A104KSBBA0R, Rapid code 11-3442](https://www.rapidonline.com/suntan-ts170r2a104ksbba0r-0-1uf-10-100v-x7r-2-54mm-radial-ceramic-capacitor-11-3442) | Receiver filtering and transmitter decoupling |
| ✅ | 10 | 4.7 µF electrolytic capacitors | [JB Capacitors JRK1H4R7M015000400070000B, Rapid code 11-4117](https://www.rapidonline.com/jb-capacitors-jrk1h4r7m015000400070000b-4-7uf-50v-20-4x7mm-mini-radial-alum-cap-11-4117) | Receiver filtering and transmitter decoupling; observe polarity |
| ✅ | 10 | Tactile push buttons | [Diptronics DTS-644K, Rapid code 78-1150](https://www.rapidonline.com/diptronics-dts-644k-square-button-through-hole-6-x-6mm-tactile-switch-100gf-78-1150) | Trigger, reload, and menu controls; six used and four spares |
| ✅ | 2 | Full-size breadboards | [830-point full-size breadboard (£5 each), The Pi Hut](https://thepihut.com/products/full-sized-breadboard) | One complete player circuit per breadboard |
| ✅ | 1 box | Breadboard jumper wires | [140-piece 22 AWG solid jumper kit (£4), The Pi Hut](https://thepihut.com/products/jumper-wire-kit-140-piece) | Connects PiCowbell GPIO, receivers, display, buttons, and IR driver |
| ✅ | 2 | Micro-USB data/charging cables | [Official Raspberry Pi Micro-USB cable (£1.20 each), The Pi Hut](https://thepihut.com/products/raspberry-pi-micro-usb-cable) | Programming and charging; one cable per player |

Expected component cost is roughly **£90 before delivery**, based on the
listed prices and typical Rapid pack pricing. No soldering iron is required for
this breadboard build.

## Already required but not purchased here

- a computer with a USB-A port; for a USB-C-only computer, buy two
  [USB-C to Micro-USB data cables](https://thepihut.com/products/usb-c-to-micro-usb-cable-black)
  instead of the USB-A cables listed above;
- a private 2.4 GHz Wi-Fi network or phone hotspot;
- a modern web browser;
- a safe, non-flammable surface on which to test and charge the LiPo batteries.

The game server runs on the computer during prototyping, so a Raspberry Pi
server and dedicated router are not required yet.

## Identify the parts

Open [`parts.svg`](parts.svg) next to the bags. It shows every resistor with
its colour bands, both capacitors, the IR LED, the TSOP receiver, the BC337,
and the tactile button.

## Important assembly notes

- Select **Pico 2 W with headers**, not a headerless board, so it plugs into
  the PiCowbell without soldering. Pico 2 (no W) has no Wi-Fi.
- Confirm each LiPo's red wire aligns with `+` on the PiCowbell before plugging
  it in. Never force or reverse a JST connector.
- Charge batteries where they can be observed. Do not use a battery that is
  swollen, bent, punctured, hot, or otherwise damaged.
- Power the prototype IR LED from regulated `3V3 OUT` through two series 15 Ω
  resistors and the BC337-40. Never drive it directly from a GPIO. Do not use
  `VSYS` here: its voltage rises while USB is connected and would increase LED
  current.
- Verify BC337-40 collector/base/emitter order from its datasheet; it differs
  from many 2N2222-family parts.
- The two series 15 Ω emitter resistors form a conservative 30 Ω starting
  value. Measure pulse current before attempting maximum range or reducing it.
- Electrolytic capacitors are polarized. Ceramic capacitors are not.
- Use infrared LEDs only. Never substitute a laser diode.

## Explicitly deferred

Do not buy these until the breadboard game works:

- wearable receiver cables and harnesses;
- trigger microswitches and panel-mounted controls;
- soldering equipment, perfboard, JST connectors, and hookup wire;
- enclosures and 3D-printed parts;
- buzzers, vibration motors, decorative lights, and optics;
- dedicated Raspberry Pi server or travel router;
- larger batteries.

The 500 mAh cells are intended to prove rechargeable operation, not establish
final match duration. Battery capacity will be selected after measuring the
complete player's average and peak current.

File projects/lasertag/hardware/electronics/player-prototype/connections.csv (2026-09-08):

reference | value_or_part | pin_1 | pin_1_net | pin_2 | pin_2_net | pin_3 | pin_3_net | pin_4 | pin_4_net
A1 | Adafruit 5906 Proto Doubler PiCowbell | Pico socket | ALL_PICO_HEADER_PINS | JST positive | VBAT | JST negative | GND | slide switch | 3V3_EN
U1 | Raspberry Pi Pico 2 W | 36 | +3V3 | 38 | GND | 39 | VSYS | 40 | VBUS
R1 | 15 ohm 1 W | 1 | +3V3 | 2 | IR_R_MID
R4 | 15 ohm 1 W | 1 | IR_R_MID | 2 | IR_LED_A
D1 | Vishay TSAL6200 | A | IR_LED_A | K | IR_SWITCH
Q1 | Diotec BC337-40 | C | IR_SWITCH | B | Q1_BASE | E | GND
R2 | 220 ohm | 1 | IR_TX | 2 | BASE_R_MID
R5 | 220 ohm | 1 | BASE_R_MID | 2 | Q1_BASE
R3 | 10 kohm | 1 | Q1_BASE | 2 | GND
C1 | 4.7 uF electrolytic | + | +3V3 | - | GND
C2 | 100 nF ceramic | 1 | +3V3 | 2 | GND
DS1 | SSD1306 OLED module | VCC | +3V3 | GND | GND | SDA | OLED_SDA | SCL | OLED_SCL
SW1 | trigger button | 1 | BTN_TRIGGER | 2 | GND
SW2 | reload button | 1 | BTN_RELOAD | 2 | GND
SW3 | menu button | 1 | BTN_MENU | 2 | GND
R10 | 100 ohm | 1 | +3V3 | 2 | RX_FRONT_VS
C10 | 100 nF ceramic | 1 | RX_FRONT_VS | 2 | GND
C11 | 4.7 uF electrolytic | + | RX_FRONT_VS | - | GND
U2 | Vishay TSOP38238 | 1 | RX_FRONT | 2 | GND | 3 | RX_FRONT_VS
R11 | 100 ohm | 1 | +3V3 | 2 | RX_BACK_VS
C12 | 100 nF ceramic | 1 | RX_BACK_VS | 2 | GND
C13 | 4.7 uF electrolytic | + | RX_BACK_VS | - | GND
U3 | Vishay TSOP38238 | 1 | RX_BACK | 2 | GND | 3 | RX_BACK_VS
R12 | 100 ohm | 1 | +3V3 | 2 | RX_LEFT_VS
C14 | 100 nF ceramic | 1 | RX_LEFT_VS | 2 | GND
C15 | 4.7 uF electrolytic | + | RX_LEFT_VS | - | GND
U4 | Vishay TSOP38238 | 1 | RX_LEFT | 2 | GND | 3 | RX_LEFT_VS
R13 | 100 ohm | 1 | +3V3 | 2 | RX_RIGHT_VS
C16 | 100 nF ceramic | 1 | RX_RIGHT_VS | 2 | GND
C17 | 4.7 uF electrolytic | + | RX_RIGHT_VS | - | GND
U5 | Vishay TSOP38238 | 1 | RX_RIGHT | 2 | GND | 3 | RX_RIGHT_VS

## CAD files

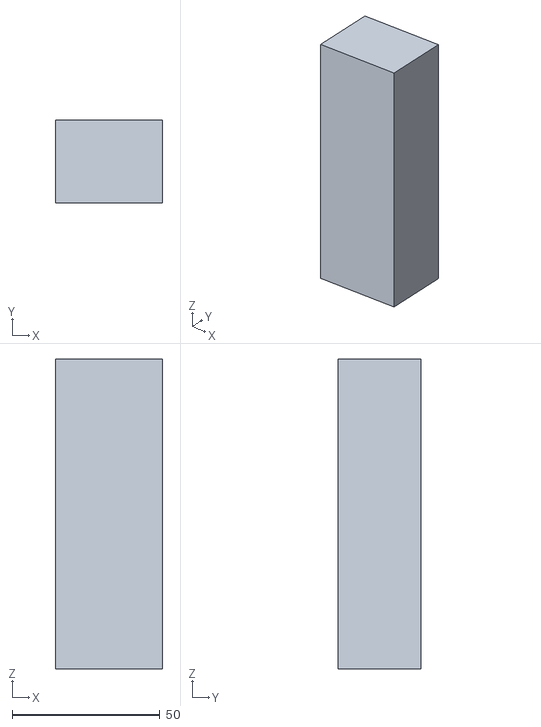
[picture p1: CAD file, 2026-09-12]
projects/gun/cad/stl/magazine.stl
36.2 x 28.0 x 105.0

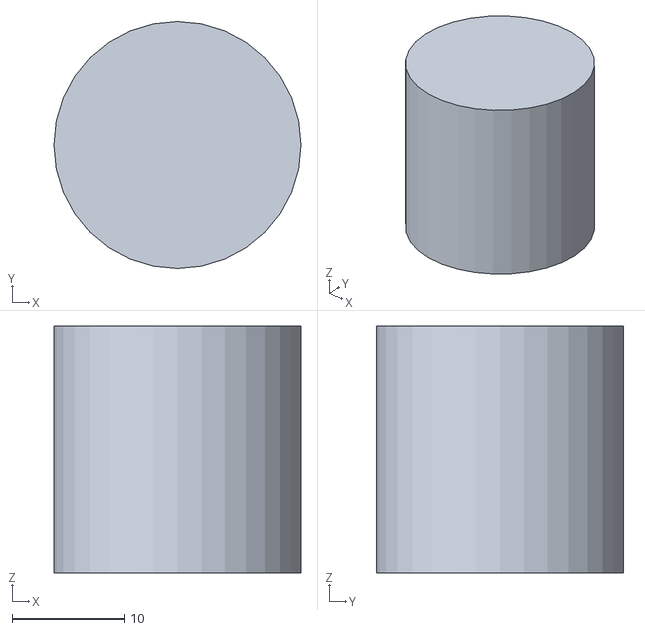
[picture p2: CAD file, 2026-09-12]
projects/gun/cad/stl/muzzle_collar.stl
22.0 x 22.0 x 22.0

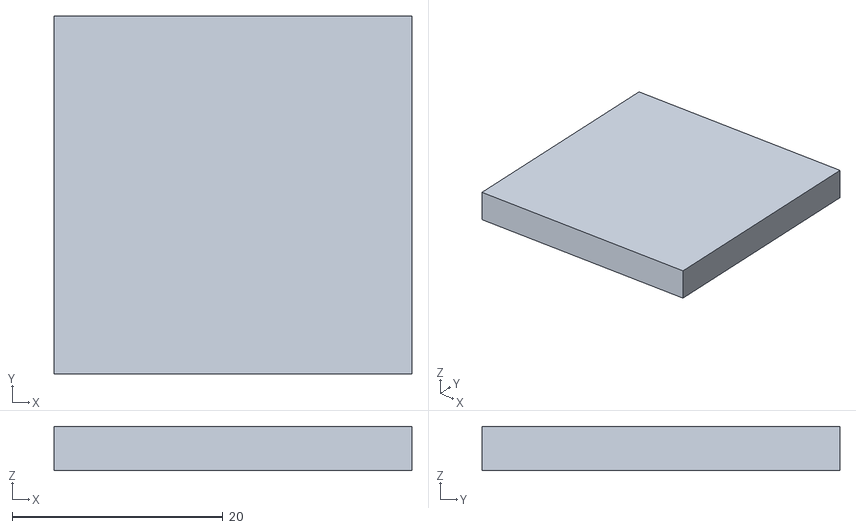
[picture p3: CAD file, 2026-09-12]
projects/gun/cad/stl/oled_bezel.stl
34.0 x 34.0 x 4.20

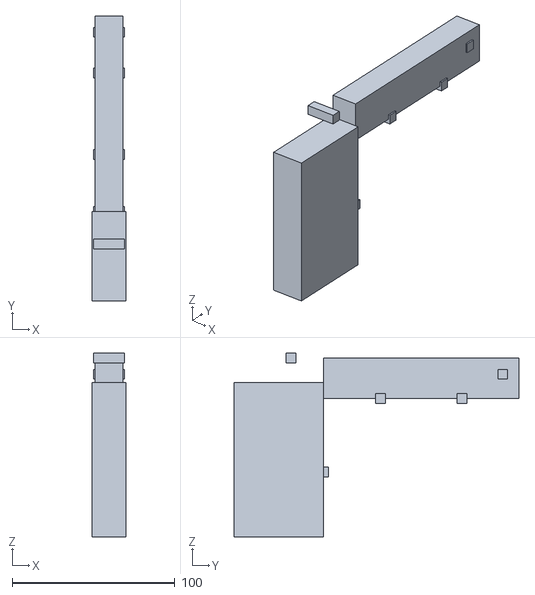
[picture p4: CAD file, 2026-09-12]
projects/gun/cad/stl/frame_left.stl
21.0 x 175.0 x 113.0

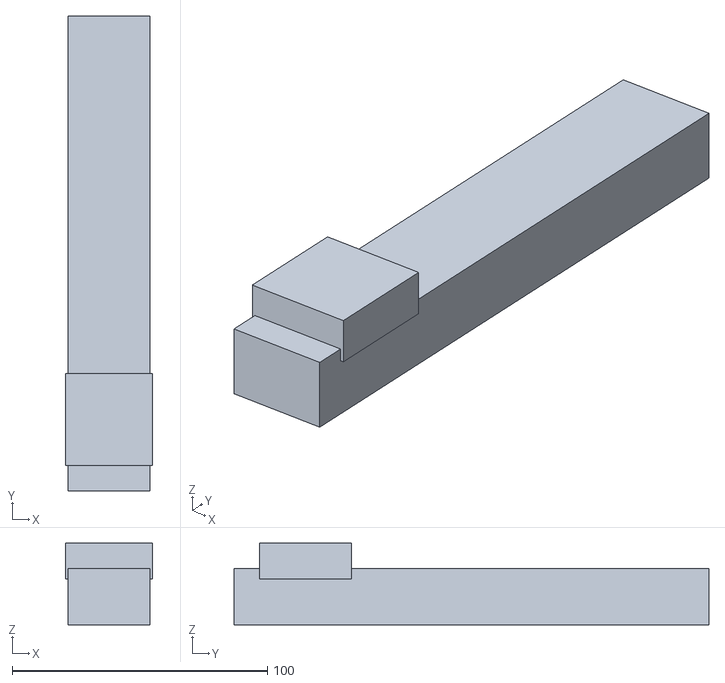
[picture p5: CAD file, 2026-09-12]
projects/gun/cad/stl/slide.stl
34.0 x 186.0 x 32.0

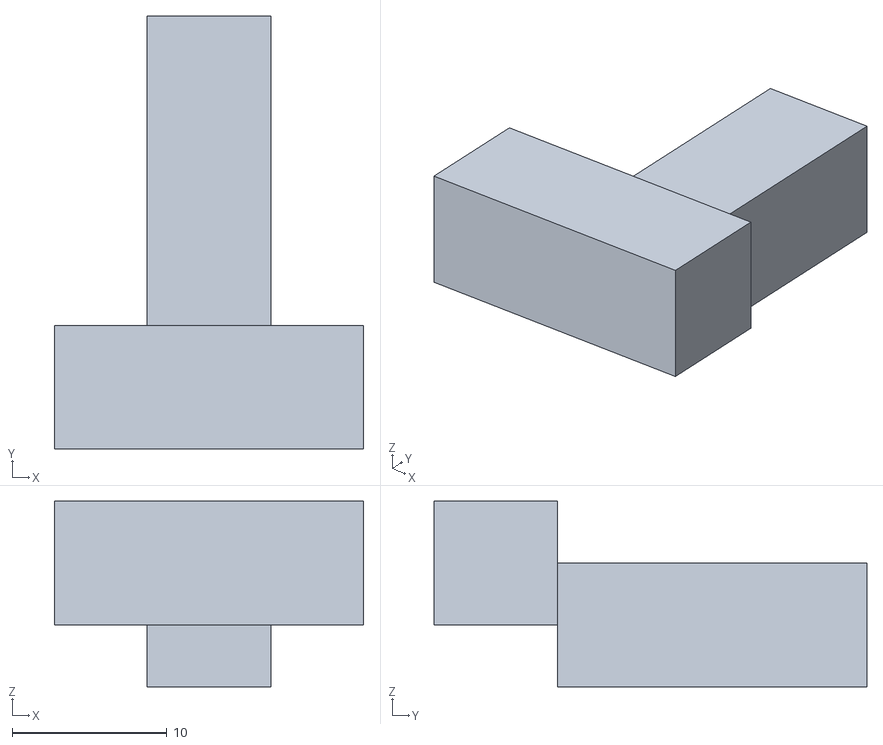
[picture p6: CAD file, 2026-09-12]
projects/gun/cad/stl/trigger.stl
20.0 x 28.0 x 12.0

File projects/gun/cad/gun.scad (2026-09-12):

// Laser-tag gun shell — Glock 17 Gen5 proportions, electronics-real packing.
// Units: millimetres. Vanilla OpenSCAD (no BOSL).
//
// Part select:
//   part = "preview" | "frame_left" | "frame_right" | "slide"
//        | "trigger" | "magazine" | "muzzle_collar" | "oled_bezel"
//
// Measure your OLED PCB and LiPo before a long print; tweak the named
// constants below if pockets are tight.

part = "preview";

// --- Glock 17 Gen5 starting envelope (then widened for parts) ---
overall_length = 202;
overall_height = 139;
frame_width    = 42;   // real ~34; widened for Pico + wiring
slide_width    = 32;   // real 25.5; widened for OLED PCB
slide_length   = 186;
barrel_length  = 114;
trigger_reach  = 70;   // trigger face from backstrap reference
wall           = 2.4;
clearance      = 0.35;
screw_d        = 2.2;  // clearance for M2
screw_boss     = 6;

// --- Electronics pockets (measure and edit) ---
pico_l = 52;   // 51 mm PCB + USB overhang allowance
pico_w = 21.5;
pico_h = 12;   // board + headers + wires
usb_cut_l = 16;
usb_cut_w = 10;
usb_cut_h = 8;
bootsel_d = 4.5;

oled_pcb_l = 28;
oled_pcb_w = 28;
oled_pcb_h = 6;
oled_glass_l = 24;
oled_glass_w = 14;
oled_tilt_deg = 12;

lipo_l = 36;
lipo_w = 31;
lipo_h = 7;    // 5 mm cell + foam
mag_outer_w = frame_width - 2 * wall - 1;
mag_outer_d = 28;
mag_outer_h = 105;

led_d = 5.5;
led_recess = 18;
barrel_id = 8;
barrel_od = 14;

btn_xy = 6.5;
btn_h  = 5;
trigger_pin_d = 2.2;

eps = 0.02;
$fn = 48;

module rounded_rect(size, r) {
    x = size[0]; y = size[1]; z = size[2];
    hull() {
        for (sx = [-1, 1], sy = [-1, 1])
            translate([sx * (x / 2 - r), sy * (y / 2 - r), 0])
                cylinder(h = z, r = r);
    }
}

module pico_keepout() {
    // Vertical in backstrap: USB toward heel (−Y), antenna toward beavertail (+Y)
    cube([pico_w + 2 * clearance, pico_l + 2 * clearance, pico_h + 2 * clearance], center = true);
}

module usb_keepout() {
    translate([0, -(pico_l / 2 + usb_cut_l / 2 - 1), 0])
        cube([usb_cut_w, usb_cut_l, usb_cut_h], center = true);
}

module oled_keepout() {
    cube([oled_pcb_w + 2 * clearance, oled_pcb_l + 2 * clearance, oled_pcb_h + 2 * clearance], center = true);
}

module led_keepout() {
    rotate([0, 90, 0])
        cylinder(h = led_recess, d = led_d + clearance, center = true);
}

module button_keepout() {
    cube([btn_xy + clearance, btn_xy + clearance, btn_h + clearance], center = true);
}

// Frame outline in X (width) × Y (length forward) × Z (height up)
// Origin: grip back heel, floor of mag well-ish; +Y toward muzzle, +Z up.
module frame_outer() {
    // Grip block
    translate([0, 18, 45])
        rounded_rect([frame_width, 55, 95], 4);
    // Dust cover / under-barrel
    translate([0, 95, 95])
        rounded_rect([frame_width - 4, 110, 28], 3);
    // Trigger guard loop (solid then hollowed)
    translate([0, 52, 28])
        rounded_rect([frame_width - 6, 42, 36], 3);
    // Beavertail / backstrap upper
    translate([0, 8, 100])
        rounded_rect([frame_width - 2, 28, 40], 3);
}

module frame_hollow() {
    // Mag well
    translate([0, 22, 42])
        cube([mag_outer_w - 2, mag_outer_d - 2, mag_outer_h], center = true);
    // Trigger guard opening
    translate([0, 55, 22])
        rounded_rect([frame_width, 28, 22], 6);
    // Pico cavity in backstrap (USB at heel)
    translate([0, 10, 55])
        rotate([8, 0, 0]) {
            pico_keepout();
            usb_keepout();
        }
    // Wire channel grip → barrel
    translate([0, 70, 88])
        cube([8, 90, 10], center = true);
    // IR nest cavity under muzzle
    translate([0, 150, 92])
        cube([frame_width - 10, 40, 18], center = true);
    // Barrel bore through dust cover
    translate([0, 100, 100])
        rotate([0, 90, 0])
            cylinder(h = barrel_length + 20, d = barrel_id, center = true);
    // LED recess at muzzle
    translate([0, 168, 100])
        led_keepout();
    // Trigger switch pocket
    translate([0, 48, 55])
        button_keepout();
    // Trigger pivot hole
    translate([0, 42, 62])
        rotate([0, 90, 0])
            cylinder(h = frame_width + 4, d = trigger_pin_d + clearance, center = true);
    // BOOTSEL access (left side when assembled — cut in both halves for symmetry)
    translate([-frame_width / 2 + 1, 6, 70])
        rotate([0, 90, 0])
            cylinder(h = wall + 4, d = bootsel_d);
    // Screw bosses tunnels
    for (p = screw_points())
        translate(p)
            cylinder(h = frame_width + 4, d = screw_d, center = true);
}

function screw_points() = [
    [0, 5, 20],
    [0, 5, 90],
    [0, 35, 110],
    [0, 90, 85],
    [0, 140, 85],
    [0, 165, 100],
    [0, 55, 40],
    [0, 20, 40]
];

module screw_bosses() {
    for (p = screw_points())
        translate(p)
            rotate([0, 90, 0])
                cylinder(h = frame_width - 2, d = screw_boss, center = true);
}

module frame_solid() {
    difference() {
        union() {
            frame_outer();
            screw_bosses();
        }
        frame_hollow();
        // Split plane chamfer helper: thin kerf for mating faces is handled by half()
    }
}

module frame_half(side) {
    // side = -1 left (negative X), +1 right
    difference() {
        intersection() {
            frame_solid();
            translate([side * (frame_width / 2 + 50) / 2, overall_length / 2, overall_height / 2])
                cube([frame_width / 2 + 50, overall_length + 40, overall_height + 40], center = true);
        }
        // Mating face relief
        translate([0, overall_length / 2, overall_height / 2])
            cube([clearance, overall_length + 50, overall_height + 50], center = true);
    }
}

module slide_body() {
    difference() {
        union() {
            translate([0, slide_length / 2 - 5, 118])
                rounded_rect([slide_width, slide_length, 24], 2);
            // Optic hump at rear
            translate([0, 28, 132])
                rotate([-oled_tilt_deg, 0, 0])
                    rounded_rect([slide_width + 2, oled_pcb_l + 8, 14], 2);
        }
        // OLED pocket
        translate([0, 28, 134])
            rotate([-oled_tilt_deg, 0, 0]) {
                oled_keepout();
                // Glass window
                translate([0, 0, 6])
                    cube([oled_glass_w, oled_glass_l, 10], center = true);
            }
        // Wire slot down into frame
        translate([0, 40, 115])
            cube([6, 20, 20], center = true);
        // Lightening / barrel clearance
        translate([0, 110, 112])
            cube([slide_width - 8, 100, 10], center = true);
        // Muzzle collar seat
        translate([0, 175, 118])
            cylinder(h = 20, d = barrel_od + 1, center = true);
    }
}

module trigger_body() {
    difference() {
        union() {
            // Finger face
            translate([0, 0, 0])
                hull() {
                    translate([0, 0, 0]) cylinder(h = 8, d = 10, center = true);
                    translate([0, 18, -6]) cylinder(h = 6, d = 8, center = true);
                }
            // Pivot ear
            translate([0, -6, 4])
                cube([frame_width - 14, 8, 10], center = true);
        }
        // Pivot hole
        translate([0, -6, 4])
            rotate([0, 90, 0])
                cylinder(h = frame_width, d = trigger_pin_d + clearance, center = true);
        // Pad that presses the tactile switch
        translate([0, 4, -8])
            cube([4, 4, 6], center = true);
    }
}

module magazine_body() {
    difference() {
        rounded_rect([mag_outer_w, mag_outer_d, mag_outer_h], 2);
        // Cell pocket
        translate([0, 0, 8])
            cube([lipo_w + clearance, lipo_h + clearance, lipo_l + 4], center = true);
        // Foam / lead channel to top (toward JST in mag well)
        translate([0, 0, mag_outer_h / 2 - 10])
            cube([10, 8, 30], center = true);
        // Finger grooves (cosmetic, shallow)
        for (z = [-30, -10, 10, 30])
            translate([mag_outer_w / 2 - 1, 0, z])
                rotate([0, 90, 0])
                    cylinder(h = 3, d = 12, center = true);
    }
}

module muzzle_collar_body() {
    difference() {
        cylinder(h = 22, d = barrel_od + 8);
        translate([0, 0, -eps])
            cylinder(h = 24, d = barrel_od + clearance);
        // LED aperture
        translate([0, 0, 12])
            cylinder(h = 12, d = led_d + 1);
        // Flat for glue / set-screw (optional)
        translate([barrel_od / 2 + 2, 0, 11])
            cube([4, 8, 10], center = true);
    }
}

module oled_bezel_body() {
    difference() {
        rounded_rect([oled_pcb_w + 6, oled_pcb_l + 6, 4], 1.5);
        // Window
        translate([0, 0, -eps])
            cube([oled_glass_w + 0.5, oled_glass_l + 0.5, 6], center = true);
        // Clip recesses
        for (sx = [-1, 1])
            translate([sx * (oled_pcb_w / 2 + 1), 0, 1])
                cube([2, 8, 3], center = true);
    }
}
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

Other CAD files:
projects/gun/cad/stl/frame_right.stl

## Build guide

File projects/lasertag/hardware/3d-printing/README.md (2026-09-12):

# 3D-printing placeholder

No enclosure geometry lived here yet. The first printable gun shell is now in
[`projects/gun/cad/`](../../../gun/cad/): Glock 17–proportioned OpenSCAD sources,
STLs, and print notes for the Pico / OLED / mag-battery / IR LED packing.

This directory will still collect later shared parts:

- body receiver pods with a clear IR field of view;
- wearable harness clips and strain relief;
- revised gun revisions after field testing.

## Requirements to capture before CAD

- final PCB, battery, connector, switch, and screen dimensions;
- emitter field of view and optical alignment;
- receiver visibility and protection from direct impacts;
- hand sizes, ambidextrous use, mass, balance, and glove clearance;
- rounded edges, recessed fasteners, ventilation, and service access;
- rigid LiPo protection against bending, puncture, crushing, and direct impact;
- access to the power button and Micro-USB charging port without exposing the battery;
- cable snag prevention and breakaway behavior;
- printer tolerances, wall thickness, material, and assembly method.

Use temporary project boxes until these measurements are stable. A future
design review must cover mechanical safety and local rules for realistic
weapon-shaped objects before public use.

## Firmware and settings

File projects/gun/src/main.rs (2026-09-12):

//! Pico 2 W gun: trigger press sends a NEC IR burst. Optional USB serial debug mode.

#![no_std]
#![no_main]

mod board;
mod cli;
mod display;
mod ir;
mod led;
mod settings;

use core::fmt::Write as _;
use core::sync::atomic::{AtomicBool, Ordering};
use embassy_executor::Spawner;
use embassy_futures::select::{Either3, select3};
use embassy_rp::block::ImageDef;
use embassy_rp::clocks::RoscRng;
use embassy_rp::flash::Flash;
use embassy_rp::gpio::{Input, Pull};
use embassy_rp::i2c::{self, I2c};
use embassy_sync::blocking_mutex::raw::CriticalSectionRawMutex;
use embassy_sync::channel::Channel;
use embassy_time::{Duration, Timer};
use heapless::String;
use panic_halt as _;

use crate::settings::ConfigFlash;

#[unsafe(link_section = ".start_block")]
#[used]
static IMAGE_DEF: ImageDef = ImageDef::secure_exe();

#[unsafe(link_section = ".bi_entries")]
#[used]
static PICOTOOL_ENTRIES: [embassy_rp::binary_info::EntryAddr; 4] = [
    embassy_rp::binary_info::rp_program_name!(c"gun"),
    embassy_rp::binary_info::rp_cargo_version!(),
    embassy_rp::binary_info::rp_program_description!(c"Pico 2 W laser-tag gun + OLED"),
    embassy_rp::binary_info::rp_program_build_attribute!(),
];

/// NEC address. Command is rolled 1..=10 on each send.
const ADDR: u8 = 0x42;

/// Clicks from the button task. Capacity covers presses during a NEC send.
static CLICKS: Channel<CriticalSectionRawMutex, (), 8> = Channel::new();
/// `true` while GP19 is low (button closed or wired as a dead short).
static BTN_HELD: AtomicBool = AtomicBool::new(false);

enum DebugLed {
    AlwaysOn,
    Beacon,
}

#[embassy_executor::main]
async fn main(spawner: Spawner) {
    let p = embassy_rp::init(Default::default());

    let mut flash: ConfigFlash = Flash::new_blocking(p.FLASH);
    settings::replace(settings::load_flash(&mut flash)).await;
    led::start(
        spawner, p.PIN_23, p.PIN_25, p.PIN_24, p.PIN_29, p.PIO0, p.DMA_CH0,
    )
    .await;
    cli::start(spawner, p.USB, flash);

    // GP18 → 220 Ω → BC337 base. LED current is from 3.3 V. Idle is low.
    let mut ir = ir::IrLed::new(p.PIN_18);
    // GP19 to GND through the tactile switch. Pull-up so open = high.
    let mut button = Input::new(p.PIN_19, Pull::Up);
    // Schmitt rejects weak/slow breadboard contacts. Off so a brief press counts.
    button.set_schmitt(false);
    spawner.spawn(button_task(button).unwrap());

    let mut i2c_config = i2c::Config::default();
    i2c_config.frequency = 100_000;
    let i2c = I2c::new_blocking(p.I2C0, p.PIN_17, p.PIN_16, i2c_config);
    let mut screen = display::Screen::new(i2c);
    let mut presses: u32 = 0;

    loop {
        if settings::snapshot().await.debug {
            run_debug(&mut ir, &mut screen, &mut presses).await;
            ir.idle();
        } else {
            run_normal(&mut ir, &mut screen, &mut presses).await;
            ir.idle();
        }
    }
}

/// Button click sends one NEC burst. USB `debug on` + `save` leaves this loop.
async fn run_normal(
    ir: &mut ir::IrLed,
    screen: &mut display::Screen,
    presses: &mut u32,
) {
    drain_clicks();
    let mut line = idle_line();
    screen.show(line.as_str(), btn_status(), *presses, btn_high());
    loop {
        match select3(
            CLICKS.receive(),
            settings::wait_change(),
            Timer::after_millis(200),
        )
        .await
        {
            Either3::First(()) => {
                *presses = presses.saturating_add(1);
                let cmd = random_cmd();
                line = sent_line(cmd);
                screen.show(line.as_str(), btn_status(), *presses, btn_high());
                ir.send_nec(ADDR, cmd).await;
            }
            Either3::Second(()) => return,
            Either3::Third(()) => {
                if line.as_str() == "ready" || line.as_str() == "btn short?" {
                    line = idle_line();
                }
                screen.show(line.as_str(), btn_status(), *presses, btn_high());
            }
        }
    }
}

/// Button toggles LED DC on vs NEC every 1 s. USB `debug off` + `save` leaves.
async fn run_debug(
    ir: &mut ir::IrLed,
    screen: &mut display::Screen,
    presses: &mut u32,
) {
    drain_clicks();
    let mut mode = DebugLed::AlwaysOn;
    loop {
        if !settings::snapshot().await.debug {
            return;
        }
        match mode {
            DebugLed::AlwaysOn => {
                ir.dc_on();
                screen.show("always on", "debug DC", *presses, btn_high());
                match select3(
                    CLICKS.receive(),
                    settings::wait_change(),
                    Timer::after_millis(200),
                )
                .await
                {
                    Either3::First(()) => {
                        ir.idle();
                        *presses = presses.saturating_add(1);
                        mode = DebugLed::Beacon;
                    }
                    Either3::Second(()) => {
                        if !settings::snapshot().await.debug {
                            ir.idle();
                            return;
                        }
                    }
                    Either3::Third(()) => {
                        screen.show("always on", "debug DC", *presses, btn_high());
                    }
                }
            }
            DebugLed::Beacon => {
                screen.show("every 1s", "debug NEC", *presses, btn_high());
                loop {
                    if !settings::snapshot().await.debug {
                        ir.idle();
                        return;
                    }
                    let cmd = random_cmd();
                    screen.show("every 1s", "sending", *presses, btn_high());
                    ir.send_nec(ADDR, cmd).await;
                    screen.show("every 1s", "debug NEC", *presses, btn_high());
                    match select3(
                        CLICKS.receive(),
                        Timer::after(Duration::from_secs(1)),
                        settings::wait_change(),
                    )
                    .await
                    {
                        Either3::First(()) => {
                            ir.idle();
                            *presses = presses.saturating_add(1);
                            mode = DebugLed::AlwaysOn;
                            break;
                        }
                        Either3::Second(()) => {}
                        Either3::Third(()) => {
                            if !settings::snapshot().await.debug {
                                ir.idle();
                                return;
                            }
                        }
                    }
                }
            }
        }
    }
}

fn drain_clicks() {
    while CLICKS.try_receive().is_ok() {}
}

/// GPIO interrupt on low. Do not require the pin to stay low for tens of
/// milliseconds — a tactile contact on a breadboard is often shorter than that.
#[embassy_executor::task]
async fn button_task(mut button: Input<'static>) {
    loop {
        while button.is_low() {
            BTN_HELD.store(true, Ordering::Relaxed);
            Timer::after_millis(10).await;
        }
        BTN_HELD.store(false, Ordering::Relaxed);
        button.wait_for_low().await;
        BTN_HELD.store(true, Ordering::Relaxed);
        led::flash();
        let _ = CLICKS.try_send(());
        Timer::after_millis(30).await;
    }
}

fn btn_high() -> bool {
    !BTN_HELD.load(Ordering::Relaxed)
}

fn btn_status() -> &'static str {
    if btn_high() {
        "press btn"
    } else {
        "btn held"
    }
}

fn idle_line() -> String<12> {
    let mut line = String::new();
    let _ = line.push_str(if btn_high() { "ready" } else { "btn short?" });
    line
}

fn random_cmd() -> u8 {
    (RoscRng::next_u8() % 10) + 1
}

fn sent_line(cmd: u8) -> String<12> {
    let mut line = String::new();
    let _ = write!(line, "sent 42:{cmd:02X}");
    line
}

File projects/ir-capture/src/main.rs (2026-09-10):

//! Pico 2 W: TSOP38238 IR capture on SH1106 OLED, USB provisioning, Wi-Fi POST.

#![no_std]
#![no_main]

mod board;
mod cli;
mod display;
mod ir;
mod settings;
mod wifi;

use embassy_executor::Spawner;
use embassy_futures::select::{Either, select};
use embassy_rp::block::ImageDef;
use embassy_rp::flash::Flash;
use embassy_rp::gpio::{Input, Pull};
use embassy_rp::i2c::{self, I2c};
use embassy_time::{Duration, Instant, Timer};
use panic_halt as _;

use crate::settings::ConfigFlash;

#[unsafe(link_section = ".start_block")]
#[used]
static IMAGE_DEF: ImageDef = ImageDef::secure_exe();

#[unsafe(link_section = ".bi_entries")]
#[used]
static PICOTOOL_ENTRIES: [embassy_rp::binary_info::EntryAddr; 4] = [
    embassy_rp::binary_info::rp_program_name!(c"ir-capture"),
    embassy_rp::binary_info::rp_cargo_version!(),
    embassy_rp::binary_info::rp_program_description!(c"Pico 2 W TSOP38238 capture + Wi-Fi POST"),
    embassy_rp::binary_info::rp_program_build_attribute!(),
];

#[embassy_executor::main]
async fn main(spawner: Spawner) {
    let p = embassy_rp::init(Default::default());

    let mut flash: ConfigFlash = Flash::new_blocking(p.FLASH);
    settings::replace(settings::load_flash(&mut flash)).await;

    let stack = wifi::start(
        spawner, p.PIN_23, p.PIN_25, p.PIN_24, p.PIN_29, p.PIO0, p.DMA_CH0,
    )
    .await;
    cli::start(spawner, p.USB, flash);

    // GP18 (physical pin 24) is wired to the TSOP38238 OUT pin.
    //
    // `Input` means this GPIO only *reads* voltage; we never drive 3.3 V or
    // 0 V ourselves (that would fight the sensor). `Pull::Up` enables the
    // Pico's internal resistor to 3.3 V so an idle or disconnected line reads
    // high. The TSOP is idle-high anyway and has its own pull-up; this is
    // belt and braces. See `ir.rs` for how high/low map onto IR marks/spaces.
    let mut ir_pin = Input::new(p.PIN_18, Pull::Up);
    let mut i2c_config = i2c::Config::default();
    i2c_config.frequency = 100_000;
    // Same OLED pins as temperature-display: GP17 SCL, GP16 SDA.
    let i2c = I2c::new_blocking(p.I2C0, p.PIN_17, p.PIN_16, i2c_config);
    let mut screen = display::Screen::new(i2c);

    // Last fully-decoded NEC or Samsung address/command. Repeat frames
    // (button held) do not contain those bytes, so decode() reuses this
    // event. `None` until the first non-repeat success.
    let mut last: Option<ir::Event> = None;
    let mut received: u32 = 0;
    let mut last_count_key: Option<(u8, u16, u8)> = None;
    let mut last_count_at = Instant::from_ticks(0);
    let mut main_line = heapless::String::<16>::new();
    let _ = main_line.push_str("ready");
    screen.show(main_line.as_str(), wifi::status_line(), ir_pin.is_high(), received);

    loop {
        // Race the IR *wait* against a 300 ms tick — not the capture itself.
        //
        // `select` completes when *either* future finishes. The IR side sleeps
        // until the TSOP pin falls. Capture is a busy loop and must not be
        // cancelled by the timer. The tick refreshes the OLED Wi-Fi/POST
        // status and the title H/L pin indicator even when nobody is pressing
        // a remote. Whichever loses is dropped; that is fine: a new
        // `wait_for_falling_edge` is created next iteration, and the timer is
        // restarted.
        match select(ir_pin.wait_for_falling_edge(), Timer::after_millis(300)).await {
            Either::First(()) => {
                let frame = ir::capture_busy(&ir_pin);
                // Falling edge then almost no further edges: pin went low and
                // stayed there (short, swapped VS/OUT, etc.).
                if frame.durations_us.len() < 2 {
                    screen.show("stuck L", wifi::status_line(), ir_pin.is_high(), received);
                    Timer::after_millis(200).await;
                    continue;
                }

                let mut event = ir::decode(&frame, last);
                // First copy after AGC, or a later copy caught mid-frame while
                // we were drawing/POSTing, often fails as `raw`. The sender
                // emits two more full frames ~40 ms apart — grab those.
                for _ in 0..2 {
                    if ir::is_structured(&event) {
                        break;
                    }
                    match select(
                        ir_pin.wait_for_falling_edge(),
                        Timer::after_millis(100),
                    )
                    .await
                    {
                        Either::First(()) => {
                            let retry = ir::capture_busy(&ir_pin);
                            if retry.durations_us.len() >= 2 {
                                let next = ir::decode(&retry, last);
                                if ir::is_structured(&next) {
                                    event = next;
                                }
                            }
                        }
                        Either::Second(()) => break,
                    }
                }
                if ir::is_structured(&event) {
                    // Swallow the rest of the sender's triple burst.
                    Timer::after_millis(220).await;
                }
                // Remember address/command only for a full frame, never for a
                // repeat (that would just write the same pair again).
                match event {
                    ir::Event::Nec {
                        repeat: false, ..
                    }
                    | ir::Event::Samsung {
                        repeat: false, ..
                    } => {
                        last = Some(event);
                    }
                    _ => {}
                }
                count_event(&event, &mut received, &mut last_count_key, &mut last_count_at);
                main_line = ir::oled_line(&event);
                screen.show(main_line.as_str(), wifi::status_line(), ir_pin.is_high(), received);
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

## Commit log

2026-09-08 Pico 2W
    [connections.csv]
2026-09-09 Comment the IR capture path for software engineers new to electronics. (#1)
    Walk through TSOP38238 idle-high output, mark/space timings, busy-sample
    capture, and NEC decode in ir.rs, and explain the GP18 pull-up and select
    loop that drives it from main.
2026-09-10 Fix button
2026-09-12 Gun wip
    [frame_left.stl, frame_right.stl, gun.scad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]
